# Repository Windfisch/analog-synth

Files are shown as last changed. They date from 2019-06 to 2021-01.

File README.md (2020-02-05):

# Analog Synthesizer Project

This project attempts to build a **low-cost** analog synthesizer based on
well-available components like LM324 or TL084 op-amps, which is **easy
to understand and learn**.

The goal is a semimodular synthesizer which is compatible to existing other
systems, where possible. The following features are planned:

- two 1-Volt-per-octave voltage controlled oscillators (VCO) with triangle,
  PWM-able square, and sawtooth waveforms
- the option to use them as digital controlled oscillators (DCO)
- a voltage controlled filter (VCF)
- a voltage controlled amplifier (VCA)
- digital or analog envelope generators
- analog waveshaping and distortion circuits
- USB or MIDI interface based on a STM32 microcontroller

For the sake of simplicity, the following trade-offs are being made:

- exact component selection is traded for automatic or semiautomatic tuning
  where possible:
- no exact 1-volt-per-octave frequency behaviour: The VCO's frequency response
  is not 100% perfect. While commercial synthesizers offer complex analog
  compensation circuitry, this project will measure the frequency deviation
  and compensate for it in software at the stage of the
  MIDI-to-Control-Voltage interface.
- no voltage controlled analog envelopes: These are complicated to build, and
  the difference to digital envelopes or LFOs is not noticeable.

## Required Hardware

So far, apart from standard resistors and capacitors, the synth uses LM324 op
amps, and BC547 / 2N3904 bipolar-junction-transistors and 2N7000 MOSFETs.

The control logic and its firmware is currently based upon a STM32F103 based
*"blue pill"* board, which can be sourced for less than 2 EUR from your
favourite chinese seller. ([Note: look for those boards with a rectangular white reset
switch, not a flat round one.](bluepill.md))
Previous versions were developed for the
[STM32F411 discovery board](https://www.st.com/en/evaluation-tools/32f411ediscovery.html),
which should still work after adjusting the Makefile.

## Repo Contents

under `simulation/`, some circuitry was tested (using the KiCAD SPICE
simulation).

Most importantly, `simulation/vco` shows a functional exponential VCO. There
are detailed annotations on which part serves which purpose.

[simulation/software/](simulation/software/) contains tooling to do transient
simulation on parts of the synth with different control voltages and to further analyze
the results.

Under `measure_vco/` you can find the tooling and test results for measuring
the pitch deviation of the VCO.

[hardware/](hardware/) contains the actual hardware boards and drafts:

  - The [VCO development board mk I](hardware/vco_mk1).
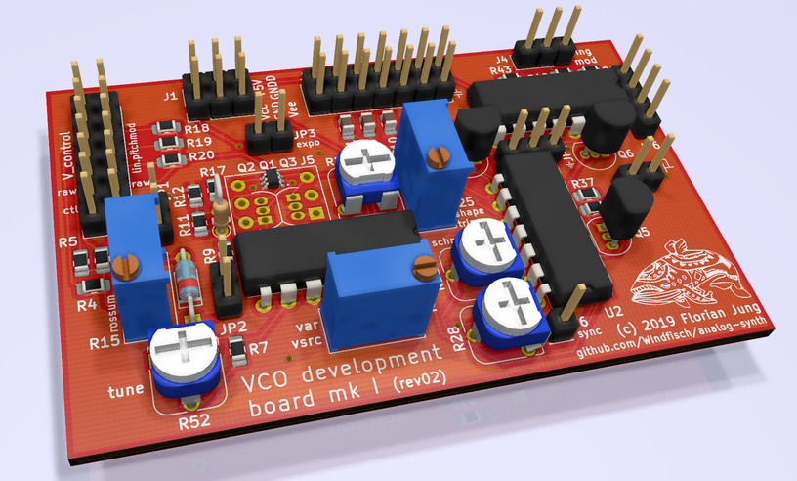
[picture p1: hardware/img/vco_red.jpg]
    
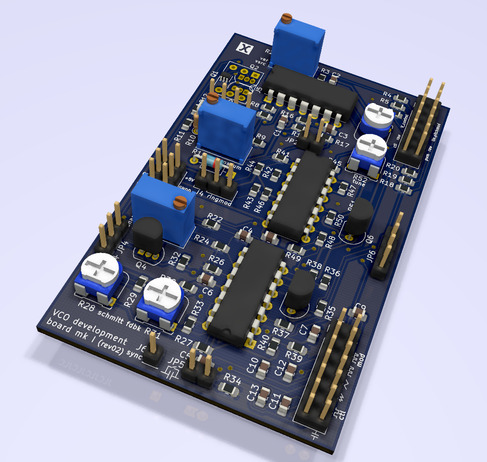
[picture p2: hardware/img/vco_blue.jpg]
    
  - A [voice supplement board](hardware/voice_board) containing a VCA, VCF and
    some utility functions.
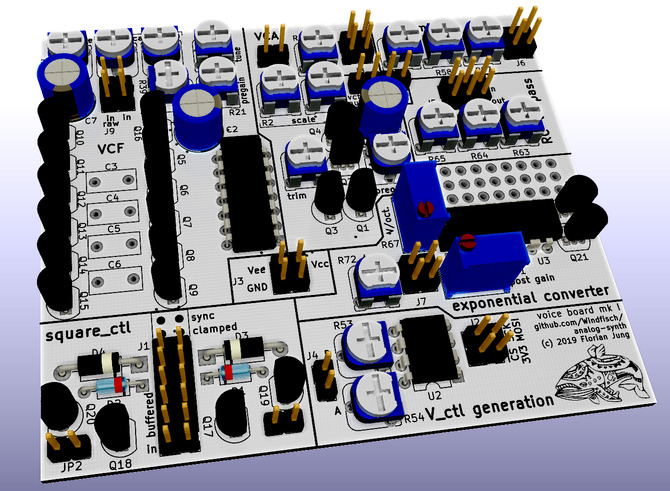
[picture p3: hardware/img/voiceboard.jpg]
render of the board
    
  - A [main control board](hardware/control_board_prototype) with a STM32 blue
    pill board, utility DACs and the supply voltage generation.
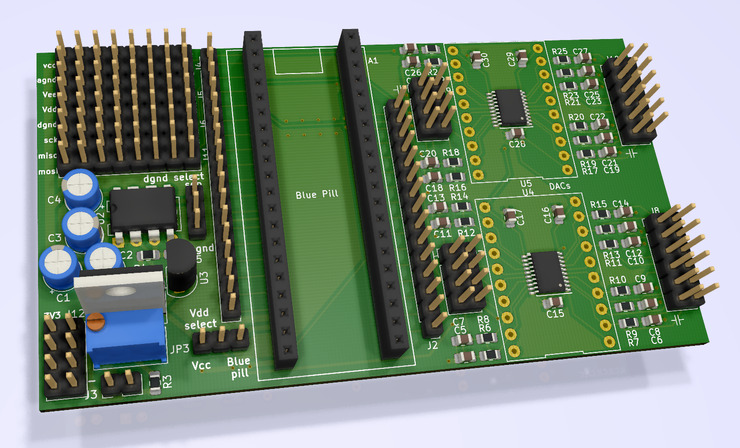
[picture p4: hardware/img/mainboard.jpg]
render of the board
    

## Setup

To build libopencm3:

```
git submodule update --init
make -j8 -C libopencm3
```

If you're using a STM32F411 board, you must adjust `measure_vco/firmware/Makefile`
and use the `DEVICE=stm32f411re` instead of the `DEVICE=stm32f103c8t` line.

To measure the vco frequency response:

```
cd measure_vco/firmware
make
```

then do whatever is neccessary to flash the program onto your board. For the blue
pill board, putting it into bootloader mode by jumpering BOOT0 to 1, resetting, and
calling `stm32flash -w dac_test.bin /dev/ttyUSB0` does the job, while for my
STM32F411-discovery, which has a non-standard blackmagic firmware on the STLINK chip, it is:

```
arm-none-eabi-gdb dac_test.elf # make sure it loads the .gdbinit file
load
run
```

Connect the pins correctly, then record the output with an UART adapter
(or using the blackmagic uart device).

## Licensing

All software, firmware and schematics are released under the terms of the [GPL3 license](LICENSE.md).
Note that this does not include the `simulation/**/*.lib` files needed for
simulation. Vendor licensing as noted in the respective files applies.

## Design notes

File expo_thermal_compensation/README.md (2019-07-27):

# Designing a thermal compensation for the exponential converter

The exponential converter used in the VCO has a temperature dependency that
affects its volt-per-octave setting. To be precise, the expo converter
is described by the following formula:

```
I_out = const * exp(V_in / V_T)
```

where `V_T` denotes the _thermal voltage_ of the transistor, which is
calculated as

```
V_T = k * T / q
```

with `k` being the [Boltzmann Constant](https://en.wikipedia.org/wiki/Boltzmann_constant),
`T` denoting the temperature in [Kelvin](https://en.wikipedia.org/wiki/Kelvin) and
`q` being the [elementary charge](https://en.wikipedia.org/wiki/Elementary_charge).

This means that since room temperature is roughly at 300K = 27C, a change in temperature
by 3 degrees changes the argument of exp(...) by ±1%. So at 24C, our 1V/oct VCO may
actually require only 0.99V/oct, and at 30C, it may need 1.01V/oct.

Over a range of plus minus three octaves, the highest and lowest note would be
`1200 * 3 * 0.01` = 36 cents off!

## Compensating using a NTC

In order to compensate for this, we can employ a resistor network containing
an NTC resistor, that changes its resistance in dependence of the temperature.

Instead of feeding the actual control voltage into the expo converter, we run it
through a voltage divider which counteracts the transistor behaviour.

The network looks as follows, with R3 being the NTC. The control voltage is fed
into `(in)`, while `(out)` goes into the expo converter.

```
                 +----[R2]----+
(in) ----[R1]----+            +------+----- [R4] ---- GND
                 +----[R3]----+      |
                                   (out)
```

## Finding the right values

A commonly available NTC is the
[Vishay NTCLE100E3 series](https://www.vishay.com/docs/29049/ntcle100.pdf).

Their datasheet describes their resistance using the following formula:

```
R_T = R_ref * exp(A + B/T + C/T² + D/T³)
```

where A,B,C and D are listed in the table on page four. The values differ
for different `R_ref` values as described in the datasheet.

`find_values.py` performs a brute-force search over possible values for
R1 to R4 and outputs a list of possible combinations and their maximum
deviation.

Using this approach, up to 0.3 cent per octave deviation can be achieved
over a temperature range from 18 to 30 degrees celsius.

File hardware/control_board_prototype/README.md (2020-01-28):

Control Board mk I
==================

The main board of the synth: It accepts a STM32F103 Blue Pill board and offers
two 10-channel DACs. Additionally, it contains a voltage converter, a virtual
ground circuit and pin headers for power distribution.

render of the board

Setup
-----

Adjust to R2 to 540 Ohms to get a supply voltage of 10V.

U3 is optional. If U3 is equipped, do not close JP1. (C1, C2, R4 and R5 can
be left out in this case.) Otherwise, do close JP1.

JP2 controls whether the digital ground is connected to the analog ground, or
whether DGND is a separate buffered voltage source.

Similarly, JP3 allows to switch between the analog supply voltage and the
blue pill board's 5V supply voltage.

Recommended configuration
-------------------------

**Use Vdd = Vcc (JP3).** Taking Vdd from the blue pill board creates weird
"digital singing" on the audio signal.

**Use a separate dgnd (JP2).** Joining agnd and dgnd together causes strong
humming (approx. 100Hz; I measured 116Hz?!) and buzzing (from the SPI
bus; completely goes away as long the BU2505FV DAC isn't used (i.e.,
during startup/init), reduced when the MCP4822 isn't connected to the
SPI bus, very present when it is). Using a separate GND completely
cancels the humming, and reduces the buzzing to ~-70-80dB when the
VCA is closed, but still audible if the VCA is open).

A **TLE2426** ground splitter (U3) seems to be **unneccessary**.

Revisions
---------

- rev01: Has no marking and no wind fish on the back side.
- rev02: Small overlapping silk screen fixes. Has a wind fish and "rev02" on the back side. Was never fabricated.

Tested configuration
--------------------

rev01 has been used successfully with the following configuration:

- U2 was changed to TL072.
- JP1 closed, U3 not equipped.
- JP2 (dgnd select) in *sep* configuration.
- JP3 (Vdd select) in *blue pill* configuration.
- right half of the DAC section (i.e. J8, J10 and associated resistors
  and capacitors) not populated.

Fabrication
-----------

The gerber outputs used for fabrication of rev01 with [JLCPCB](https://jlcpcb.com) are
located under `fab/`.

The fabrication layers indicating which component values to put where
are [here](../voice_and_control_board_fab.pdf).

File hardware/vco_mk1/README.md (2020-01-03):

VCO development board mk I
==========================

This board is designed to test several options for the VCO design. It
features:

  - Triangle, pulse and sawtooth wave generation
  - shape adjust (R25). Tune this so that you get a perfect triangle.
  - volt-per-octave input
  - linear and exponential frequency modulation
  - selectable capacitor-coupling for the triangle wave using JP5
  - Boundary adjust: R27-R31. (Increases triangle amplitude while
    lowering its frequency)
  - Rossum compensation ([details](https://www.schmitzbits.de/expo_tutorial/)
    [(or on archive.org)](https://web.archive.org/web/20191216173852/https://www.schmitzbits.de/expo_tutorial/))
    for compensating the pitch drop at higher pitches. Can be enabled by
    closing JP2 and disabled by closing JP1 instead. Optionally, R13-15 and
    D1 need not be equipped when disabled
  - Low frequency trim by connecting Q4's source to some millivolts around
    GND instead of GND directly using JP4. Optionally, R1-R3 can be spared
    if not used.
  - DCO mode by applying a square wave to ctl\_override in J2
  - soft sync mode by applying a narrow open-drain pulse to J6
    (e.g. 99% high impedance, 1% connected-to-GND)
  - Digital ringmodulation on the triangle/sawtooth and the square wave,
    configured through JP6 as follows:
    
    - close 12 and 34 for ring-modulated sawtooth
    - close 12 only for ring-modulated triangle
    - close 23 for no ring modulation. U3, Q6 and R41-50 need not be
      equipped then.

There are two different board layouts:

  - [one smaller double-sided layout](vco_mk1_windfisch)
    render of the board
  - [one larger layout with components only on the top side](vco_mk1_spitfire), contributed by [SpitfireX](https://github.com/spitfirex).
    render of the board

Revisions
---------

**rev01** can be identified by the marking _"VCO development board mk I"_
(without revision id). Both layouts have been fabricated by [JLCPCB](https://jlcpcb.com)
using the gerber outputs in `gerber-rev01/` or `fab-rev01/`.
Please see the Errata below.

**rev02** can be identified by the text _"VCO development board mk I (rev02)"_.
It has never been fabricated as it contains only silk screen bug fixes.
The differences to rev01 are:

  - U2 is rotated by 180 degrees, swapping U2A/U2C and U2B/U2D, respectively.
  - The pictograms around J3 have been rearranged in the correct order.

Errata (rev01)
--------------

U2 has Vcc and Vee swapped in the schematic. This can be resolved by inserting
U2 into the socket "the wrong way" (i.e. the notch is not on the side where the
PCB wants to have the notch).

SpitfireX's board has the pictograms around J3 reversed. This affects both
the signal pictograms as well as the marking for the capacitor-coupled outputs.

These are fixed in rev02.

Differences from the schematic (rev01)
--------------------------------------

  - U2 is reversed (see Errata)
  - Q1 was equipped, J5, Q2 and Q3 weren't
  - R2 was replaced by a 20k poti
  - R15 was not equipped (no rossum compensation)
  - R18-20 were not equipped yet
  - R10 is missing (no thermal compensation)
  - R9 was replaced by a 100 Ohm resistor
  - R8 was replaced by 10k
  - R4,5,6 were populated with 470k, 220k and 100k, respectively

Testing the board
-----------------

1. Do not equip R15. Close JP1, but not JP2 to disable the rossum compensation.
2. Do not equip U3, and put a jumper on JP6's pins 2+3 to disable ring modulation.
3. Put a jumper on JP4 so that GND is connected.
4. Connect Vcc, GND and Vee to +6V, 0V and -6V (approx.). This configuration can be
   achieved e.g. by a 12 V voltage source, a 1:1 resistor divider and a LM324/LM358
   in buffer configuration for GND.
5. Connect the capacitor-coupled triangle output on J3 to your sound card. Connect GND
   via a capacitor to your sound card.
6. You should hear a triangle wave that can be tuned with R52, R21 (and R31).

Further usage scenarios
-----------------------

### Using the pwm input

The PWM comparator's input is floating. Either connect a voltage source / poti to it that
can range from Vee to Vcc, or tie it to GND using a jumper on J2.

### Tuning the center frequency

Close the JP3 jumper. This will disable the control voltage input and force it to the
"center position". R52 (tune) will be useless. R21 can be used to tune the frequency
at the center position. This is the pitch where the oscillator will exhibit no thermal
drift; the "V/oct" drift (which is compensated by R9-R12, but not perfectly) will
develop around the center pitch. The farther away from this center pitch, the worse the
drift will be.

### Adjusting the schmitt trigger's operation

The triangle's amplitude and pitch can be adjusted by R31.

The triangle's center voltage can be adjusted with R28. This is only relevant when JP5 is
closed, directly attaching the triangle signal to the sawtooth generation circuitry,
bypassing the coupling capacitor. In this case, tuning R28 is required to achieve a clean
sawtooth signal where all teeth are at the same voltage levels.

### Tuning the frequency response

By equipping the Rossum compensation circuitry, closing JP2 and opening JP1, Rossum
compensation can be tuned using R15. This changes the frequency response at high pitches.

By not jumpering GND, but the variable voltage source on JP4, R2 can be used to affect
the frequency response at low pitches.

### Square-like waveform

Connect `square_ctl` to the ring mod input J4. Ideally do not connect it directly,
but buffer the signal using an emitter follower or similar. Loading `square_ctl` will
severly affect the pitch. Then listen to the pulse-mod signal while changing the pwm
voltage on J2.

Soldering workflow
------------------

I soldered the boards in my [local FabLab](https://fablab.fau.de), using a thermal
controlled soldering iron with a flat (screwdriver-like) tip (maybe 1-2mm wide).

I had a printed [BOM](vco_mk1_windfisch/bom.ods) next to me, where I ticked
every component.

Notes for various components:

  - *Resistors and capacitors*: for each component value, do:
    - for each occurence do:
      1. put some tin on one of the pads
      2. heat the tinned pad while sliding the component onto the pad
      3. solder the other pad
    - difficulty: easy
  - *BCM847*: using a stereo microscope, do:
    - 1. use *lots* of flux
    - 2. put some tin on a pad, slide the component onto it
    - 3. more flux
    - 4. solder all pins of the opposite side. Ignore any solder bridges
    - 5. same for the other side.
    - 6. remove the solder bridges by applying flux, then sliding the cleaned
         soldering iron away from the pins. This will take away some tin, until
         finally the solder bridge vanishes due to the surface tension.
    - difficulty: advanced with good equipment, impossible without
  - *through hole components*: straightforward, easy. Order them from flat to large.

Lessons learned
---------------

A capacitor-coupled GND terminal would be useful.

When connecting `square_ctl` to J6 (regardless of whether U3 is installed or not),
this affects the frequency by ca. a semitone. A transistor buffer might help.

Finding the component locations is hard. Prepare one copy of the board layout
per component value, with the respective components highlighted. (Maybe color
coding helps to reduce the amount of copies needed).

Greatly reduce the amount of different component values. Finding the right
component strip and peeling of the covering foil off takes a lot of time.

It might be better to prepare all resistors/capacitors at once, instead of
grouping them by value. Color coding might help.

The double-sided variant wasn't slower to solder than the single-sided.

The BC547 transistor pair don't touch, the footprint should move a bit towards
each other.

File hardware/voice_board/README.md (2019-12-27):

Voice Board mk I
================

This board offers various utility features for a two-VCO-voice. It is designed
to be used together with two [../vco_mk1/](VCO mk I boards) and offers the
following features:

  - voltage controlled filter
  - voltage controlled amplifier
  - simple mixer
  - 2x square_ctl signal processing (buffering, sync pulse generation, clamping,
    which are missing from the VCO mk I board)
  - an expo converter (to be used as VCF input)
  - a 2-channel MCP4822 DAC for VCO control voltage generation
  - three general-purpose RC low pass filters

render of the board

The gerber outputs used for fabrication with [JLCPCB](https://jlcpcb.com) are
located under `fab/`.

The fabrication layers indicating which component values to put where
are [here](../voice_and_control_board_fab.pdf).

Revisions
---------

**rev01** has no marking at the wind fish logo. It has been fabricated
using the gerber outputs in `fab-rev01/`. Please refer to the errata
below.

**rev02** can be identified by a *"rev02"* text close to the wind fish
logo. It has never been fabricated as it only contains silkscreen and
component value fixes.

Errata (rev01)
--------------

Some resistors in the sync pulse circuitry are wrong. R48 and R49 must
be changed from 10k to 1k. R50 and R51 must be changed from 1k to 10k.
This has been fixed in rev02.

R53 and R54's values are too weak, leading to very bad DAC performance
(e.g., non-monotonic DAC behaviour every 4 code points). Maybe a 100k
poti would work better; I fixed it by de-soldering the potis and wiring
U2's DAC output pins 6 and 8 to the connector J4 directly.

Errata (rev01)
--------------

R53 and R54's values are too weak, leading to very bad DAC performance
(e.g., non-monotonic DAC behaviour every 4 code points). Maybe a 100k
poti would work better; I fixed it by de-soldering the potis and wiring
U2's DAC output pins 6 and 8 to the connector J4 directly.

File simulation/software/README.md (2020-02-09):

Simulation analysis tooling
===========================

This tooling is intended to do transient simulation for various control
voltages using ngspice and to analyze the resulting time series.

GNU parallel is recommended for faster execution.

Usage
-----

To generate the netlist: Open `../vco/` in KiCAD, and export a netlist in spice format
(`vco.cir`).

To generate the joblist:

`bash generate_joblist.sh ../vco/vco.cir V2 0 5 0.5 sawtooth triangle square_ctl  > /tmp/jobs.txt`

The joblist can be executed with either `parallel < /tmp/jobs.txt` or `bash /tmp/jobs.txt`.

Results are placed in `/tmp/analog-synth-spice/`.

tooling for further analysis: run `bash generate_joblist.sh ../vco/vco.cir v2 -2 2.8 0.1 triangle sawtooth square_ctl V_control V_expo GNDREF`

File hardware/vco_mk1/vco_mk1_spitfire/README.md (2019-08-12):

Alternative PCB layout by [SpitfireX](https://github.com/spitfirex).

This design is a 2 layer PCB with all components on the front. As a result, it features a continuous ground plane on the back.

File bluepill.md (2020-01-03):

Buying the right blue pill board
================================

It appears that blue pill boards are available from at least two different
manufacturers.

- The "white switch" variant has a rectangular, high-profile white reset
  switch located close to the USB port. Also, the USB port has two mounting
  pads (one at each side). The silk screen is layouted carefully.
  bad board
- The "round switch" variant has a flat and round reset switch at the same
  location. The USB port has four mounting pads. The silk screen at the pin
  headers ("B12 B13...") is uneven, the letters don't share a common baseline.
  good board

While both variants are affected by the
[wrong USB resistor issue](https://amitesh-singh.github.io/stm32/2017/05/27/Overcoming-wrong-pullup-in-blue-pill.html)
[(or on archive.org)](https://web.archive.org/web/20190401142745/https://amitesh-singh.github.io/stm32/2017/05/27/Overcoming-wrong-pullup-in-blue-pill.html)
(tl;dr: The USB D+ pull up resistor R10 should be 1.5k, but it's populated with
10k. Some hosts don't like this, others don't care), I never had a problem with
this.

However, the "round switch" variant appears to be of worse build quality: All two
boards I bought failed to provide reliable USB connectivity, one even failed to
provide a reliable +5V power to the STM32.

I had no problems with my four samples of the "white switch" variant, so I
recommend using these.

[See also](https://wiki.relativty.net/index.php/STM32#Purchasing_your_STM32_board)
[(or on archive.org)](https://web.archive.org/web/20200103224615/https://wiki.relativty.net/index.php/STM32)

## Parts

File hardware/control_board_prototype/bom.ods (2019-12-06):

Ref | Qnty | Value | Cmp name | Footprint | Description | Vendor
A1, | 1 | BluePill | BluePill | footprints:BLUEPILL
J1, | 1 | Conn_01x17_Male | Conn_01x17_Male | Connector_PinHeader_2.54mm:PinHeader_1x17_P2.54mm_Vertical | Generic connector, single row, 01x17, script generated (kicad-library-utils/schlib/autogen/connector/)
J2, | 1 | Conn_01x15_Male | Conn_01x15_Male | Connector_PinHeader_2.54mm:PinHeader_1x15_P2.54mm_Vertical | Generic connector, single row, 01x15, script generated (kicad-library-utils/schlib/autogen/connector/)
 | 32 | One-row pin socket
J3, | 1 | Conn_01x02_Male | Conn_01x02_Male | Connector_PinHeader_2.54mm:PinHeader_1x02_P2.54mm_Vertical | Generic connector, single row, 01x02, script generated (kicad-library-utils/schlib/autogen/connector/)
JP1, | 1 | SolderJumper_2_Open | SolderJumper_2_Open | windfisch:SolderBridge | Solder Jumper, 2-pole, open
JP2, JP3, | 2 | Jumper_3_Bridged12 | Jumper_3_Bridged12 | footprints:SolderDipJumper3alt | Jumper, 3-pole, pins 1+2 closed/bridged
 | 42 | One-row pin header
J7, J9, J12, | 3 | Conn_02x04_Odd_Even | Conn_02x04_Odd_Even | Connector_PinHeader_2.54mm:PinHeader_2x04_P2.54mm_Vertical | Generic connector, double row, 02x04, odd/even pin numbering scheme (row 1 odd numbers, row 2 even numbers), script generated (kicad-library-utils/schlib/autogen/connector/)
J8, J10, | 2 | Conn_02x06_Odd_Even | Conn_02x06_Odd_Even | Connector_PinHeader_2.54mm:PinHeader_2x06_P2.54mm_Vertical | Generic connector, double row, 02x06, odd/even pin numbering scheme (row 1 odd numbers, row 2 even numbers), script generated (kicad-library-utils/schlib/autogen/connector/)
J11, J6, J4, J5, | 4 | Conn_02x10_Odd_Even | Conn_02x08_Odd_Even | Connector_PinHeader_2.54mm:PinHeader_2x08_P2.54mm_Vertical | Generic connector, double row, 02x08, odd/even pin numbering scheme (row 1 odd numbers, row 2 even numbers), script generated (kicad-library-utils/schlib/autogen/connector/)
 | 74 | Two-row pin header
C1-C4 | 4 | 1u | CP | Capacitor_THT:CP_Radial_D5.0mm_P2.50mm | Polarized capacitor
C5-C30 | 26 | 100n | C | Capacitor_SMD:C_0805_2012Metric_Pad1.15x1.40mm_HandSolder | Unpolarized capacitor
R1, | 1 | 220 | R | Resistor_SMD:R_0805_2012Metric_Pad1.15x1.40mm_HandSolder | Resistor
R2, | 1 | 1k | R_Variable | Potentiometer_THT:Potentiometer_Bourns_3296W_Vertical | Variable resistor
R3, | 1 | 1k | R | Resistor_SMD:R_0805_2012Metric_Pad1.15x1.40mm_HandSolder | Resistor
R5, R4, | 2 | 100k | R | Resistor_SMD:R_0805_2012Metric_Pad1.15x1.40mm_HandSolder | Resistor
R6-R25 | 20 | 10k | R | Resistor_SMD:R_0805_2012Metric_Pad1.15x1.40mm_HandSolder | Resistor
U1, | 1 | LM317 | LM317_3PinPackage | Package_TO_SOT_THT:TO-220-3_Vertical | 1A 35V Adjustable Linear Regulator, SOT-89/SOT-223/TO-220/TO-252/TO-263
U2, | 1 | LM358 | LM358 | Package_DIP:DIP-8_W7.62mm | Low-Power, Dual Operational Amplifiers, DIP-8/SOIC-8/TO-99-8
U3, | 1 | TLE2426xLP | TLE2426xLP | Package_TO_SOT_THT:TO-92L_Inline | Precision virtual ground, 4V to 40V input, TO-92
U4, U5, | 2 | BU2505FV | BU2505FV | footprints:SSOP20_and_breakout

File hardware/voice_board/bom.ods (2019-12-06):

Ref | Qnty | Value | Cmp name | Footprint | Description | Vendor
C1, | 1 | 470n | CP | Capacitor_THT:CP_Radial_D7.5mm_P2.50mm | Polarized capacitor
C2, C7, | 2 | 470u | CP | Capacitor_THT:CP_Radial_D7.5mm_P2.50mm | Polarized capacitor
C3, C4, C5, C6, | 4 | 47n | C | footprints:C_rect_smd_combo | Unpolarized capacitor
C8, C9, | 2 | 1n | C | Capacitor_SMD:C_0805_2012Metric_Pad1.15x1.40mm_HandSolder | Unpolarized capacitor
C10, C11, C17, | 3 | 1u | C | Capacitor_SMD:C_0805_2012Metric_Pad1.15x1.40mm_HandSolder | Unpolarized capacitor
C13, C14, C15, | 3 | any | C | Capacitor_SMD:C_0805_2012Metric_Pad1.15x1.40mm_HandSolder | Unpolarized capacitor
C16, | 1 | 10n | C | Capacitor_SMD:C_0805_2012Metric_Pad1.15x1.40mm_HandSolder | Unpolarized capacitor
D1, D2, | 2 | 3V3 | D_Zener | Diode_THT:D_DO-35_SOD27_P7.62mm_Horizontal | Zener diode
D3, D4, | 2 | 1N5817 | 1N5817 | Diode_THT:D_DO-41_SOD81_P10.16mm_Horizontal | 20V 1A Schottky Barrier Rectifier Diode, DO-41
J1, | 1 | Conn_02x06_Odd_Even | Conn_02x06_Odd_Even | Connector_PinHeader_2.54mm:PinHeader_2x06_P2.54mm_Vertical | Generic connector, double row, 02x06, odd/even pin numbering scheme (row 1 odd numbers, row 2 even numbers), script generated (kicad-library-utils/schlib/autogen/connector/)
J3, J2, J6, J7, J9, J8, | 6 | Conn_02x02_Odd_Even | Conn_02x02_Odd_Even | Connector_PinHeader_2.54mm:PinHeader_2x02_P2.54mm_Vertical | Generic connector, double row, 02x02, odd/even pin numbering scheme (row 1 odd numbers, row 2 even numbers), script generated (kicad-library-utils/schlib/autogen/connector/)
J5, | 1 | Conn_02x03_Odd_Even | Conn_02x03_Odd_Even | Connector_PinHeader_2.54mm:PinHeader_2x03_P2.54mm_Vertical | Generic connector, double row, 02x03, odd/even pin numbering scheme (row 1 odd numbers, row 2 even numbers), script generated (kicad-library-utils/schlib/autogen/connector/)
 | 21 | Two-row pin header
J4, J10, | 2 | Conn_01x02_Male | Conn_01x02_Male | Connector_PinHeader_2.54mm:PinHeader_1x02_P2.54mm_Vertical | Generic connector, single row, 01x02, script generated (kicad-library-utils/schlib/autogen/connector/)
JP1, JP2, | 2 | Jumper_2_Bridged | Jumper_2_Bridged | footprints:SolderDipJumper2alt | Jumper, 2-pole, closed/bridged
JP3, | 1 | Conn_01x04_Male | Conn_01x04_Male | footprints:SolderDipJumper4alt | Generic connector, single row, 01x04, script generated (kicad-library-utils/schlib/autogen/connector/)
 | 12 | One-row pin header
Q3, Q1, | 2 | BC327 | BC327 | Package_TO_SOT_THT:TO-92_Inline | 0.8A Ic, 45V Vce, PNP Transistor, TO-92
Q4-Q16 | 14 | BC557 | BC557 | Package_TO_SOT_THT:TO-92_Inline | 0.1A Ic, 45V Vce, PNP Small Signal Transistor, TO-92
Q17-Q21, | 4 | BC547 | BC547 | Package_TO_SOT_THT:TO-92_Inline | 0.1A Ic, 45V Vce, Small Signal NPN Transistor, TO-92
Q19, Q20, | 2 | 2N7000 | 2N7000 | Package_TO_SOT_THT:TO-92_Inline | 0.2A Id, 200V Vds, N-Channel MOSFET, 2.6V Logic Level, TO-92
R8, R46, R22, R50, R47, R51, R70, | 7 | 1k | R | Resistor_SMD:R_0805_2012Metric_Pad1.15x1.40mm_HandSolder | Resistor
R10, R9, R11, R44, R41, R37, R36, R60, R61, R38, R48, R45, R49, R62, | 14 | 10k | R | Resistor_SMD:R_0805_2012Metric_Pad1.15x1.40mm_HandSolder | Resistor
R13, R12, | 2 | 20k | R | Resistor_SMD:R_0805_2012Metric_Pad1.15x1.40mm_HandSolder | Resistor
R17, R23, R24, R33, R14, R6, R4, R3, R66, R15, | 10 | 100k | R | Resistor_SMD:R_0805_2012Metric_Pad1.15x1.40mm_HandSolder | Resistor
R25, | 1 | 47k | R | Resistor_SMD:R_0805_2012Metric_Pad1.15x1.40mm_HandSolder | Resistor
R26, | 1 | 180 | R | Resistor_SMD:R_0805_2012Metric_Pad1.15x1.40mm_HandSolder | Resistor
R27, R35, | 2 | 470 | R | Resistor_SMD:R_0805_2012Metric_Pad1.15x1.40mm_HandSolder | Resistor
R30, R29, R28, R31, | 4 | 150 | R | Resistor_SMD:R_0805_2012Metric_Pad1.15x1.40mm_HandSolder | Resistor
R32, | 1 | 220 | R | Resistor_SMD:R_0805_2012Metric_Pad1.15x1.40mm_HandSolder | Resistor
R34, | 1 | 680 | R | Resistor_SMD:R_0805_2012Metric_Pad1.15x1.40mm_HandSolder | Resistor
R43, R42, R69, | 3 | 1Meg | R | Resistor_SMD:R_0805_2012Metric_Pad1.15x1.40mm_HandSolder | Resistor
R68, | 1 | 2.5k | R | Resistor_SMD:R_0805_2012Metric_Pad1.15x1.40mm_HandSolder | Resistor
R5, | 1 | 200k | RTRIM | Potentiometer_THT:Potentiometer_Runtron_RM-065_Vertical | Trimmable resistor (preset resistor)
R7, R40, R16, R20, | 4 | 100k | R_POT | Potentiometer_THT:Potentiometer_Runtron_RM-065_Vertical | Potentiometer
R21, | 1 | 1Meg | R_Variable | Potentiometer_THT:Potentiometer_Runtron_RM-065_Vertical | Variable resistor
R53, R54, | 2 | 1k | R_POT | Potentiometer_THT:Potentiometer_Runtron_RM-065_Vertical | Potentiometer
R57, R58, R39, R1, R59, R72, R2, R19, R18, | 9 | 10k | R_POT | Potentiometer_THT:Potentiometer_Runtron_RM-065_Vertical | Potentiometer
R65, R64, R63, | 3 | any | R_Variable | Potentiometer_THT:Potentiometer_Runtron_RM-065_Vertical | Variable resistor
R67, | 1 | 200k | RTRIM | Potentiometer_THT:Potentiometer_Bourns_3296W_Vertical | Trimmable resistor (preset resistor)
R71, | 1 | 10k | RTRIM | Potentiometer_THT:Potentiometer_Bourns_3296W_Vertical | Trimmable resistor (preset resistor)
U1, | 1 | TL074 | TL074 | Package_DIP:DIP-14_W7.62mm | Quad Low-Noise JFET-Input Operational Amplifiers, DIP-14/SOIC-14
U2, | 1 | MCP4822 | MCP4822 | Package_DIP:DIP-8_W7.62mm | 2-Channel 12-Bit D/A Converters with SPI Interface and Internal Reference (2.048V)
U3, | 1 | LM324 | LM324 | Package_DIP:DIP-14_W7.62mm | Low-Power, Quad-Operational Amplifiers, DIP-14/SOIC-14/SSOP-14

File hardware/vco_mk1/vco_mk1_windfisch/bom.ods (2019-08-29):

Reference | Quantity | Value | Footprint | Datasheet
C4 | 1 | 1n | 0805 | ~
C3 | 1 | 2.2n | 0805 | ~
C1 C2 C5 C6 C7 C8 C9 C10 C11 C12 C13 | 11 | 100n | 0805 | ~
J6 | 1 | Conn_01x01_Male | Conn_01x01_Male | ~
J1 J4 | 2 | Conn_01x03_Male | Conn_01x03_Male | ~
J2 J3 | 2 | Conn_02x07_Male | Conn_02x07_Male | ~
D1 | 1 | 1N4148 | DO-35 | https://assets.nexperia.com/documents/data-sheet/1N4148_1N4448.pdf
JP1 JP2 JP3 JP5 | 4 | Conn_01x02_Male | footprints:SolderDipJumper2alt | ~
JP4 | 1 | Conn_01x03_Male | footprints:SolderDipJumper3alt | ~
JP6 | 1 | Conn_01x04_Male | footprints:SolderDipJumper4alt | ~
U1 U2 | 2 | LM324 | DIP-14 | http://www.ti.com/lit/ds/symlink/lm2902-n.pdf
U3 | 1 | 74HC86 | DIP-14 | http://www.ti.com/lit/gpn/sn74HC86
J5 | 1 | BCM847 breakout socket | DIP6-wide-ish | ~
Q1 | 1 | BCM847 | SOT-363 | http://www.onsemi.com/pub_link/Collateral/BC846BDW1T1-D.PDF
Q4 | 1 | 2N7000 | TO-92 | https://www.fairchildsemi.com/datasheets/2N/2N7000.pdf
Q6 | 1 | BC327 | TO-92 | http://www.onsemi.com/pub_link/Collateral/BC327-D.PDF
Q2 Q3 Q5 | 3 | BC547 | TO-92 | http://www.fairchildsemi.com/ds/BC/BC547.pdf
R15 | 1 | 1k | Potentiometer_Bourns_3296W_Vertical | ~
R2 R25 | 2 | 10k | Potentiometer_Bourns_3296W_Vertical | ~
R52 | 1 | 1k | Potentiometer_Runtron_RM-065_Vertical | ~
R28 | 1 | 20k | Potentiometer_Runtron_RM-065_Vertical | ~
R21 | 1 | 50k | Potentiometer_Runtron_RM-065_Vertical | ~
R31 | 1 | 1Meg | Potentiometer_Runtron_RM-065_Vertical | ~
R9 | 1 | 150 | 0805 | ~
R11 R17 R39 | 3 | 1k | 0805 | ~
R12 R40 | 2 | 2.2k | 0805 | ~
R13 | 1 | 4.7k | 0805 | ~
R27 R29 R32 R35 R41 R42 R43 R48 R49 R50 R51 | 11 | 10k | 0805 | ~
R8 | 1 | 12k2 | 0805 | ~
R23 R24 R26 | 3 | 47k | 0805 | ~
R4 R5 R6 | 3 | 147k | 0805 | ~
R14 R16 R22 R33 R36 R37 R38 R44 R45 R46 R47 | 11 | 100k | 0805 | ~
R7 | 1 | 220k | 0805 | ~
R1 R3 | 2 | 1Meg | 0805 | ~
R30 R34 | 2 | none | 0805 | ~
R18 R19 R20 | 3 | TODO | 0805 | ~
R10 | 1 | 1k NTC | Through-hole | ~

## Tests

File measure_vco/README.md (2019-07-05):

# measuring the VCO's response

This test tool will enumerate all 4096 DAC code points to generate voltages
between 0V and 2.048V which are fed into the VCO. The microcontroller will
test around 50 code points per second, listen to the signal for 5 periods,
and write out a list of the following format to its USART on pin A2:

```
codept  divider hiTicks1 loTicks1  hiTicks2 loTicks2  hiTicks3 loTicks3  hiTicks4 loTicks4  hiTicks5 loTicks5
 718      3      28751    28328     28745    28333     28742    28326     28756    28322     28752    28326
1694      9      36019    36032     36061    35997     35998    36019     36046    36013     36028    36000
3742      1      24342    23752     24350    23754     24342    23756     24340    23756     24354    23762
 414     45      39457    44456     39468    41359     39476    41358     39477    41360     39463    41366
2462      4      29918    29569     29912    29572     29900    29571     29889    29575     29896    29571
...
```

`divider` specifies the `TIM2` timer's division (in fact, it's the prescaler
plus 1). `TIM2` is clocked at 78MHz and will increment every `divider` clocks.

The hi/loTicksN can be converted into seconds by the following formula:
`time[sec] = ticks * divider / 78'000'000`, the frequency can be calculated e.g.
by `1 / (hiTicks5+loTicks5)` or -- even more precise -- `5 / (sum of all hi+loTicks)`.

older versions, which tested only 4 code points per seconds, were using the
following format.
The time is given in 10'000ths of a second. Thus, the frequency is calculated
as "(periods / (time/10000))":

```
DAC code  periods     time
point       
2048         98       2000
1024         68       1977
...
```

In both cases, the output voltage calculates as "code point * 0.5mV".

At the very beginning, two test tones close to the lowest and two close to the
highest control voltage output are played. Use the tune pot R10 to set an
offset at or close to a position where both test pairs can be heard at distinct
pitches to avoid clamping.

## experiments

[Exponential frequency response accuracy](experiments/20190625_1v_per_oct_response/README.md)

[Attribution of error artifacts to DAC or analog circuitry](experiments/20190705_error_attribution/README.md)

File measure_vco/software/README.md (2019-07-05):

Helper Tools and Software
=========================

These tools are intended to support the development process on the PC
side.

analyze\_stability.py
--------------------

This tool will analyze the frequency range, frequency gain and pulse width
behaviour of the VCO. It also supports (currently hardcoded) compensation of
the DAC "wiggle" described [here](../experiments/20190705_error_attribution).

Upon execution it will draw a plot showing the frequency deviation and the
pulse width. Also, it will output the following:

```
[2.25283296e+00 4.93029015e+03]
532.66 code points = 0.2601 Volt per octave
starting at   17.25 Hz =  -5607c distance from a4@440Hz
ending   at 3561.44 Hz =  +3620c distance from a4@440Hz
```

The numbers in the brackets define the *cent per one codepoint* and *cent offset*,
the rest should be self-explanatory.

**Usage:** `analyze_stability.py usart-dump.txt`

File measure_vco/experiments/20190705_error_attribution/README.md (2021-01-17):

Attributing errors to the DAC and to the remaining circuitry
============================================================

The frequency deviation plots show some systematic error in frequency:

First, there is a wiggle every 64 code points or so. Second, the curve
is bowl-shaped, i.e. the volt-per-octave behaviour is not constant over
the whole DAC range. Instead, it approaches a maximum, and at the left and
right of that maximum, the frequency drops flat.

It shall evaluated which of these artifacts can be attributed to the DAC
and which are to be attributed to the remaining circuitry behind the dac.

Experimental setup
------------------

Schematic and firmware from `6a28ec80e1b361b0f84615ae8e1e478800edd393`
are used. The tune pot R10 is initially adjusted so that the full range
up to the VCO's highest frequency is covered by the DAC's range. The
frequency curve was recorded into `run1.txt`.

Then, the tune pot was tuned down (`run2.txt`), even more down (`run3.txt`),
and way up (so that the high frequencies are clipped, `run4.txt`).

The resulting deviation curves are then moved along the graph (it's valid to
move a curve right by X if you move it down by the same amount X) so that
they match each other as good as possible. The shift amounts are equal to the
tuning caused by the tune pot, and are roughly consistent with the interval
I could hear while tuning.

Expectation
-----------

Any error caused by the DAC should not align across the four curves after
having them aligned as described above. Instead, it should align when
the curves are not moved in X direction. _(Reason: This error would depend
on which code point was sent to the DAC, and not on which voltage went
through U8)_

Any error caused by the circuitry behind the DAC (i.e. expo converter and VCO)
should align across the four curves. _(Reason: It does not depend on the code
point, but solely on the voltage at U8)_

Results
-------

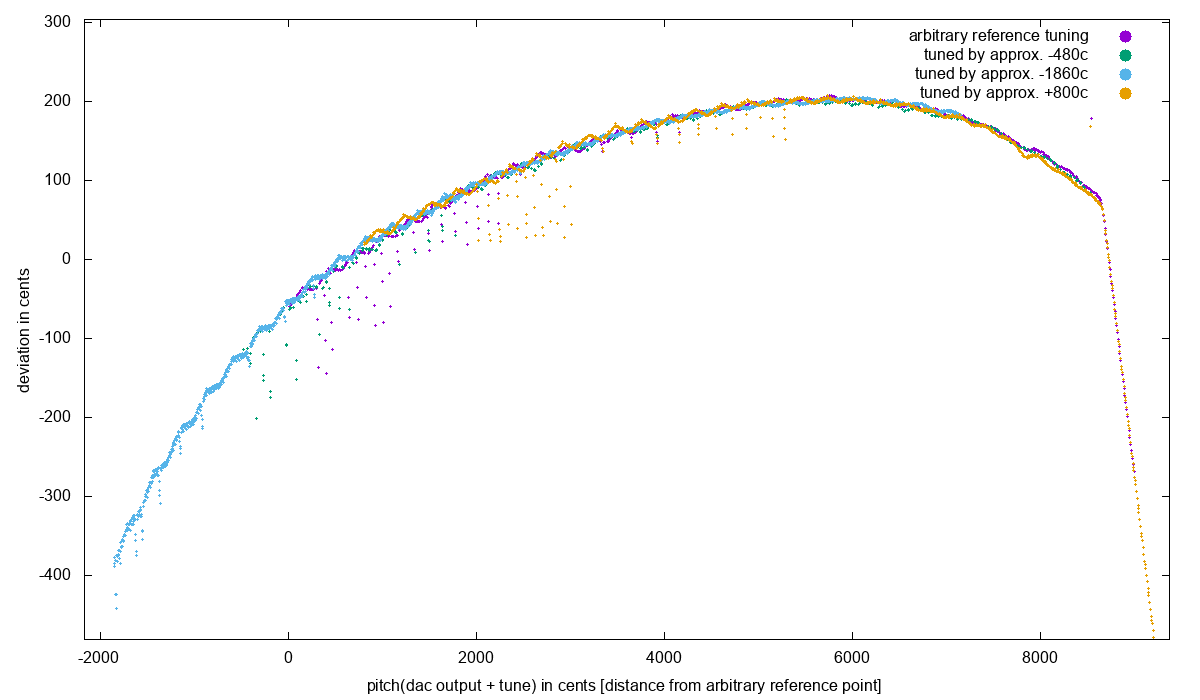
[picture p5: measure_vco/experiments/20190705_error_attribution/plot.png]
plot


The wiggle does not align. Instead, one can easily verify (not shown)
that the wiggle would align perfectly, if the X axis would show the code point,
not something proportional to the voltage through U8.

**The wiggle is a DAC linearity error and must be compensated for in firmware.**
The MCP4822 data sheet confirms this with figure 2-6 which describes "the 64 code
effect".

The overall frequency deviation perfectly aligns across the four curves.
**While it can be compensated for in firmware, it should be adressed in the
analog circuitry. Otherwise, no precise 1v/oct operation with external
(uncompensated) control voltages is possible.**

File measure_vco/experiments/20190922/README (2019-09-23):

breadboard 1: breadboard mit rossum und mit alternativen (blauen) werten fuer widerstaende
breadboard 2: ohne rossum
breadboard 3: blaue werte durch originale ersetzt (1mohm -> 100k und entsprechend das poti)
breadboard3_5.0b und ff: neu getuned.
breadboard 4: thermistor entfernt

Versorgungsspannung: 14.7V, LM317 auf 12V runter. 50-60mA verbrauch
blaues board war angeschlossen

Jumper:
JP2,3,5 offen
JP6 mittig
JP4 masse
JP1 geschlossen

format: name_x.x.{txt,png}

x.x: Amplitude des Signals in V (eingestellt via R31 (schmitt feedback))

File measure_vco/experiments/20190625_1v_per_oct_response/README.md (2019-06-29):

made with ef54a038da6c0d5c126d3517ab873899670ab93a.

All following measurements were made using a 9V block battery to power the
circuit.

```
out*.txt:               various measurements with the hand-matched 547 pair.
                        might or might have not touched the transistors during
                        measurement
2019-05-25_bcm847.txt:  measurements using the bcm847 matched transistor chip.
                        shortly but with decent time after placing the
                        transistors on the board
2019-05-25_pair*.txt:   1-3: same, but using hand-matched BC547b transistors
                        instead: these runs were started shortly after placing
                        them in the board. the runs were done subsequently with
                        almost no delay. i sat next to the setup, so they might
                        be affected by my body heat.
2019-05-25_pair.txt4:   same, longer delay, and while aerating the room
```

The following measurements were made using a regulated power supply instead:

```
2019-05-25_pair5_voltagereg.txt:    same as before, but with regulated voltage
```

The following image shows the effect of the voltage regulation on the data:

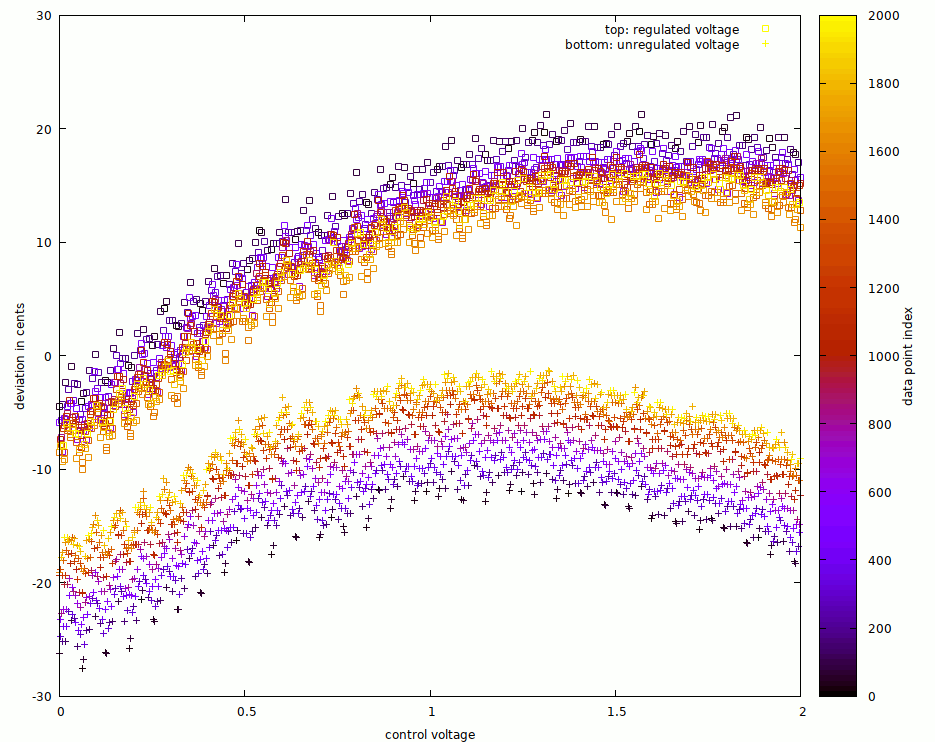
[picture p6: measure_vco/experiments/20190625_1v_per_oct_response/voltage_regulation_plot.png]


For the bottom graph without voltage regulation, the spread is much higher.
Furthermore, there is a quite linear-ish color gradient from purple (bottom)
to yellow (top), indicating that earlier data points are at a lower frequency
than late data points.

For the top graph with a regulated supply voltage, the spread / noise is
smaller, and the distribution seems more gaussian than uniform. Most
importantly, the color==time gradient is the opposite direction.

Possible explanation: The circuit's frequency depends on the supply voltage,
because the supply voltage controls the schmitt trigger thresholds. A lower
supply voltage leads to higher frequencies. The bottom graph could exhibit
the effects of a diminishing supply voltage, e.g. because the battery is
drained more and more.

The gradient for the top graph is yet to be explained. Measurement shows that
the control voltage applied to the expo converter's transistor's base is
always negative in this setup, ranging between -30mV and 0mV. During data
acquisition, the room temperature dropped a bit. (Let's say, from 303K to
300K). This changes the thermal voltage of the transistors by 1%, turning the
calibrated 1V-per-oct behaviour into 0.99V-per-oct. This, together with
the effective control voltage being negative, could explain a pitch drop
caused by a temperature drop. (For positive base-voltages, the pitch would
rise instead, and for exactly 0 V base-voltage, the pitch should not change).

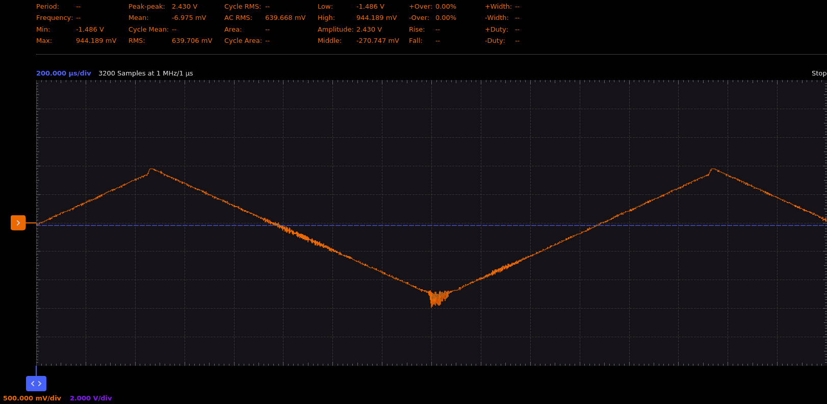
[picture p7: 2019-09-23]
measure_vco/experiments/20190922/breadboard2_2.5.png

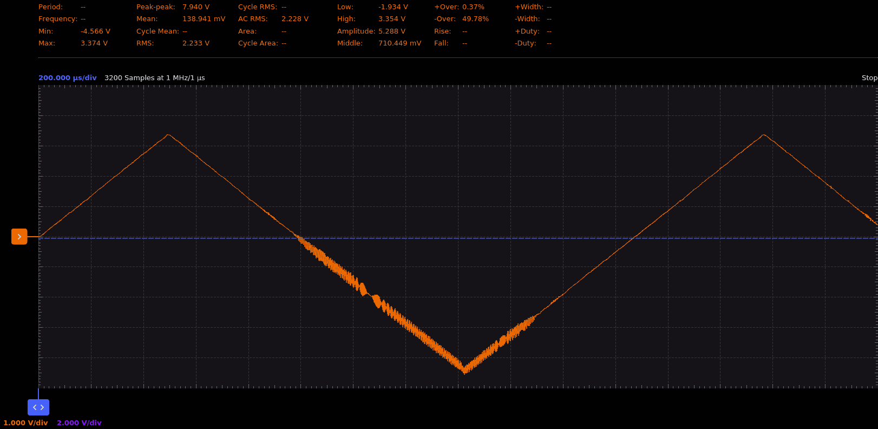
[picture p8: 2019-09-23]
measure_vco/experiments/20190922/breadboard4_8.0.png

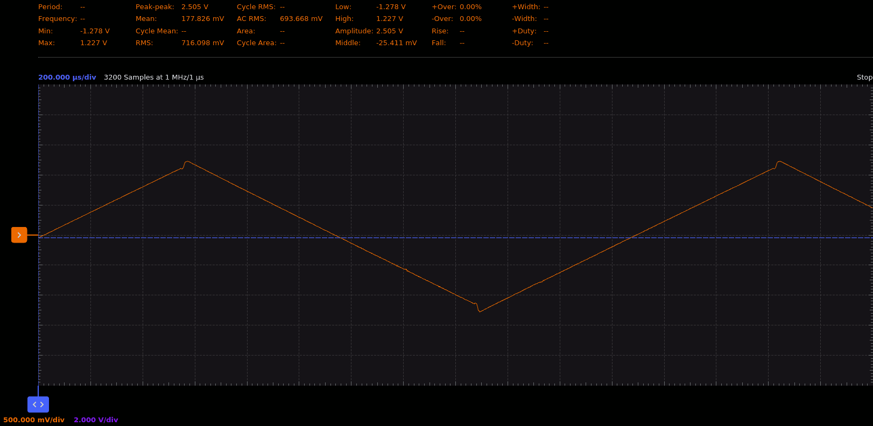
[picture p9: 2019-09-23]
measure_vco/experiments/20190922/red_2.5.png

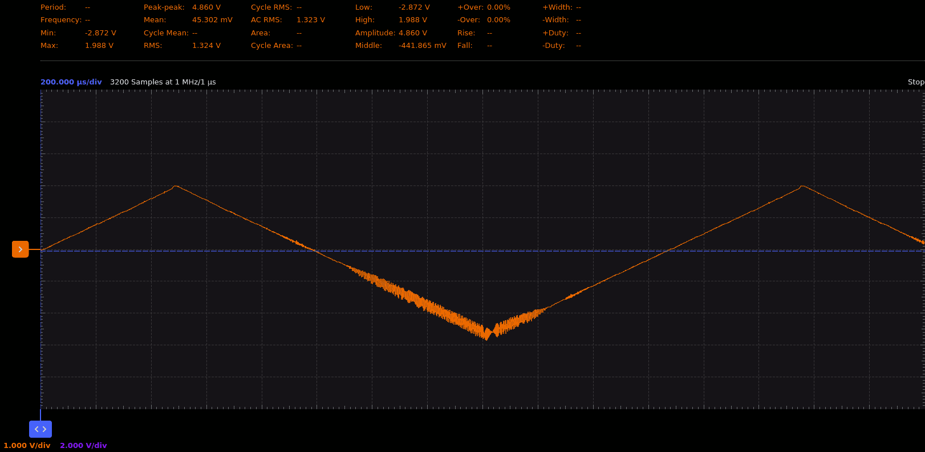
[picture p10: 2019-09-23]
measure_vco/experiments/20190922/breadboard1_5.0_000.png

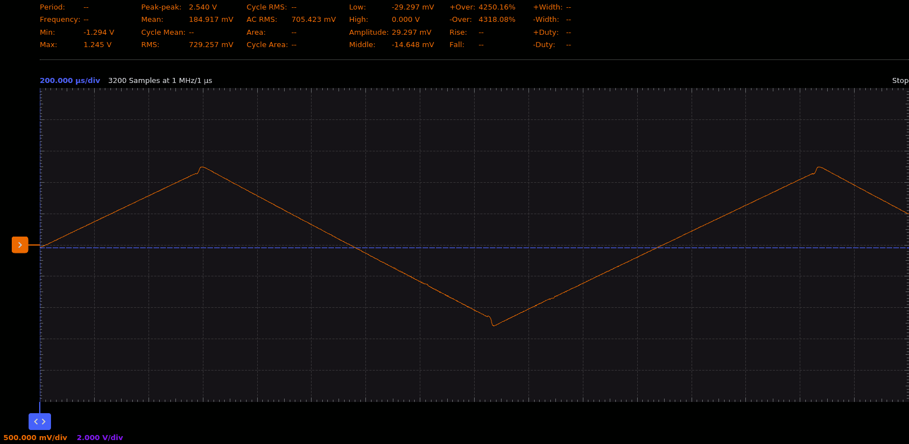
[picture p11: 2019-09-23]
measure_vco/experiments/20190922/blue_2.5.png

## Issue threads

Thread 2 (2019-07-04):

Add square ring modulator

Windfisch, 2019-07-04:
The sawtooth waveform is generated using "binary ring modulation" (i.e. by inverting the triangle's wave every half period).
Add an XOR gate (i.e., a digital multiplier) to allow binary ring modulation from outside.
Add a switch to switch between sawtooth and ring-modulated triangle.

Windfisch, 2019-08-19:
added.

Closed 2019-08-19.

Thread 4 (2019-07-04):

Automatic DAC steppiness compensation learning

Windfisch, 2019-07-04:
The DAC creates step-like artifacts every 64 code points.
- [x] they can be removed quite easily
- [ ] find an automatic way to remove them during self calibration
- [ ] do use this compensation strategy

Windfisch, 2019-11-08:
Compensation is implemented in the rust firmware.
No automatic steppiness compensation is implemented, instead, we sample every 64 code points. This automatically compensates the issue without explicitly modeling it.

Closed 2019-11-08.

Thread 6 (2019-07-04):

first order temperature compensation for the 1V-per-octave-trim

Windfisch, 2019-07-04:

Windfisch, 2019-08-19:
fixed

Closed 2019-08-19.

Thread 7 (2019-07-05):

High frequency trim

Windfisch, 2019-07-05:
Find out how to use the high frequency trim diode-resistor-combinations to resolve the volt-per-octave-tracking inaccuracy described [here](https://github.com/Windfisch/analog-synth/blob/673959eac2b995370ddffb885f70e904f58893d2/measure_vco/experiments/20190705_error_attribution/README.md)

Windfisch, 2019-07-06:
maybe an R_bulk issue, see [Sergio Franco's PhD thesis](https://ia801903.us.archive.org/1/items/hardwaredesignof677fran/hardwaredesignof677fran.pdf)

Windfisch, 2019-08-19:
Rossum compensation was implemented. For more details, see https://www.schmitzbits.de/expo_tutorial/ and search for "Rossum"

Closed 2019-08-19.

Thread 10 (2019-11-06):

Add output buffering to the square_ctl signal

Windfisch, 2019-11-06:
There is a emitter follower required to prevent the ring modulation circuitry (or any other consumer) to affect the frequency

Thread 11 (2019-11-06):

Add sync circuitry

Windfisch, 2019-11-06:
Sync works by manually applying 99%-duty-cycle PWM signals to the *sync* pin. Add circuitry to create these pulses from any input

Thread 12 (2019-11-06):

PWM ratio affects pitch

Windfisch, 2019-11-06:
Applying a LFO on the PWM ratio (regardless of whether the PWM signal is actually used or not) of VCO mk I slightly changes the pitch periodically.

Possible causes:
- GND is not perfect and thus is affected by the duty cycle / output signal of the comparator (see #13)
- OpAmp cross talk

Possible solutions:
- fix dirty ground wiring
- Change OpAmp
- Compensate using lin.pitchmod

Windfisch, 2019-11-08:
Caused by #13 and (temporarily) fixed by plugging the cable in different springs of the breadboard.

Closed 2019-11-08.

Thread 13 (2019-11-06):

Moving the ground wiring changes pitch

Windfisch, 2019-11-06:
up to half an octave!
This is likely due to the contact resistance of the cables.

Windfisch, 2019-11-08:
Seems to be a breadboard problem. Moving the cables into different slots fixes this for ca. 1 hour, then it starts getting worse.
Likely the springs are wearing out.

The cables itself, or their contact to the pin headers on the VCO board seem to be not an issue. :)

Closed 2019-11-08.

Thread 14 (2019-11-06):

Signal leaks through the closed VCA

Windfisch, 2019-11-06:
Leaking occurs even with the signal *not* being routed into the transistor's base terminal oO?
Leaking is stronger when a useless film capacitor is connected to the signal on the one side, floating on the other

Windfisch, 2019-11-08:
The signal does not leak through, but the VCA or rather, the differential-to-single-ended opamp picks up signals from the air.

It seems that the breadboard is the culprit, and also the 470uF-capacitors are both unneccessary and good antennas.

Windfisch, 2019-12-23:
This is still an issue with the new voice board.

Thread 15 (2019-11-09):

Design a control prototype board

Windfisch, 2019-11-09:
Features:
- Blue Pill socket
- 1-3x MCP4822
- 1-2x BU2505FV (plus 10x low pass filter)
- 4-16 signal shifters (0-5V to -2.5-2.5V for LFOs)
- Virtual ground generation
- Linear voltage regulator
- Capacitors
- LEDs. everyone loves them

Windfisch, 2019-11-09:
shift registers, e.g. for triggering external envelopes or leds. Just in case™!

Windfisch, 2019-11-30:
in production

Closed 2019-11-30.

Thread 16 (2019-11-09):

Design a voice supplement board

Windfisch, 2019-11-09:
Features:

- [x] mix 2-3 VCO signals
- [x] 1-3x sync circuitry
- [x] 1-3x square_ctl buffering
- [x] 1x VCA
- [x] 1x VCF (+feedback)
- [x] MCP4822
- [ ] sub oscillator
- [ ] layout board (stackable!) with separate grounds. they are joined in the main board.

Windfisch, 2019-11-09:
there should be support for fully analog VCOs (which can easily be implemented using VCO mk I)
also, for external analog envelope generators (possibly a not-yet-planned separate board)

Windfisch, 2019-11-09:
sub oscillator support! ;)

Windfisch, 2019-11-09:
make it stackable!

Windfisch, 2019-11-09:
maybe, put the MCP4822 onto this board, not on the control board.

Windfisch, 2019-11-30:
in production

Closed 2019-11-30.

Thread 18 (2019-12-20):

voice board: sync circuit does not generate a sync signal

Windfisch, 2019-12-20:
maybe the RC-highpass has a too high cutoff?

Windfisch, 2019-12-20:
R48,49 should be 1k instead of 10k

R50,51 should be 10k instead of 1k

Closed 2019-12-20.

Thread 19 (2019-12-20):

voice board: VCF does not work

Windfisch, 2019-12-20:
one transistor lane is 100mV below the other. no notable signal.
transistor mismatch? some error somewhere else?

Windfisch, 2019-12-20:
there was a solder bridge shorting Q11's collector and base terminals

Closed 2019-12-20.

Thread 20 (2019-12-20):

voice board: missing silkscreen

Windfisch, 2019-12-20:
- [x] J6
- [x] J8

Closed 2019-12-20.

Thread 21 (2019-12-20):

check voice board and main board

Windfisch, 2019-12-20:
voice board:

- [x] square_ctl buffering
- [x] clamping
- [x] sync pulse generation, see #18
- [x] VCF: broken, see #19
- [x] VCA
- [x] mixer
- [x] expo converter
- [x] Vctl generation

main board:
- [x] power generation
- [x] power distribution
- [x] STM32
- [x] DACs

Closed 2020-02-15.

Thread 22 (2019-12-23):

voice board's expo range is too low

Windfisch, 2019-12-23:

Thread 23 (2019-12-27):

voice board DAC overload

Windfisch, 2019-12-27:
The MCP4822 DAC is overloaded by the two 1k potis, yielding to negative steps in the frequency response:

```
Calibration data:
        0       10408324
        1       10412592        (+4268)
        2       10412996        (+404)
        3       10430552        (+17556)
        4       10461995        (+31443)
        5       10476525        (+14530)
        6       10471559        (+-4966)
        7       10485320        (+13761)
        8       10514117        (+28797)
        9       10531170        (+17053)
        10      10524266        (+-6904)
        11      10541212        (+16946)
        12      10571562        (+30350)
        13      10583441        (+11879)
        14      10582638        (+-803)
        15      10595078        (+12440)
        16      10623439        (+28361)
        17      10636119        (+12680)
        18      10629779        (+-6340)
        19      10646368        (+16589)
        20      10677762        (+31394)
        21      10690974        (+13212)
        22      10693401        (+2427)
        23      10703692        (+10291)
        24      10736802        (+33110)
        25      10750990        (+14188)
        26      10746097        (+-4893)
        27      10762025        (+15928)
        28      10793420        (+31395)
        29      10809007        (+15587)
        30      10806801        (+-2206)
        31      10821489        (+14688)
        32      10855301        (+33812)
        33      10868995        (+13694)
        34      10862854        (+-6141)
        35      10880101        (+17247)
        36      10909879        (+29778)
        37      10921666        (+11787)
        38      10920217        (+-1449)
        39      10935907        (+15690)
        40      10967428        (+31521)
        41      10980510        (+13082)
        42      10976635        (+-3875)
        43      10992054        (+15419)
        44      11022933        (+30879)
        45      11040306        (+17373)
        46      11036704        (+-3602)
        47      11054103        (+17399)
        48      11084608        (+30505)
        49      11102217        (+17609)
        50      11093039        (+-9178)
        51      11113498        (+20459)
        52      11140161        (+26663)
        53      11157024        (+16863)
        54      11152067        (+-4957)
        55      11165635        (+13568)
        56      11198119        (+32484)
        57      11214475        (+16356)
        58      11210262        (+-4213)
        59      11227953        (+17691)
        60      11257944        (+29991)
        61      11273733        (+15789)
        62      11267439        (+-6294)
        63      11283385        (+15946)
```

Unsoldering them and directly plugging the DAC's output into a 100k-impedance input solves this:

```
Calibration data:
        0       7560015
        1       7626153 (+66138)
        2       7685447 (+59294)
        3       7756073 (+70626)
        4       7815846 (+59773)
        5       7886242 (+70396)
        6       7946359 (+60117)
        7       8016541 (+70182)
        8       8074533 (+57992)
        9       8144614 (+70081)
        10      8204225 (+59611)
        11      8275233 (+71008)
        12      8334513 (+59280)
        13      8405362 (+70849)
        14      8467101 (+61739)
        15      8537092 (+69991)
        16      8596833 (+59741)
        17      8666389 (+69556)
        18      8725609 (+59220)
        19      8795968 (+70359)
        20      8854710 (+58742)
        21      8923339 (+68629)
        22      8981727 (+58388)
        23      9050377 (+68650)
        24      9110157 (+59780)
        25      9179110 (+68953)
        26      9238462 (+59352)
        27      9306614 (+68152)
        28      9367830 (+61216)
        29      9434346 (+66516)
        30      9494924 (+60578)
        31      9560891 (+65967)
        32      9622665 (+61774)
        33      9689127 (+66462)
        34      9748980 (+59853)
        35      9815773 (+66793)
        36      9876657 (+60884)
        37      9942616 (+65959)
        38      10003955        (+61339)
        39      10068704        (+64749)
        40      10130663        (+61959)
        41      10196342        (+65679)
        42      10256692        (+60350)
        43      10321702        (+65010)
        44      10382945        (+61243)
        45      10447593        (+64648)
        46      10508283        (+60690)
        47      10573012        (+64729)
        48      10634293        (+61281)
        49      10699242        (+64949)
        50      10759150        (+59908)
        51      10823672        (+64522)
        52      10884100        (+60428)
        53      10948259        (+64159)
        54      11010203        (+61944)
        55      11074036        (+63833)
        56      11136111        (+62075)
        57      11199193        (+63082)
        58      11259225        (+60032)
        59      11323721        (+64496)
        60      11383613        (+59892)
        61      11447449        (+63836)
        62      11507102        (+59653)
        63      11570118        (+63016)
```

Windfisch, 2021-01-31:
Fixed in 41341cb23bac400d2b9ff796438d530ec8d44693

Closed 2021-01-31.

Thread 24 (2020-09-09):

SPI clock noise

Windfisch, 2020-09-09:
The filter overlays the filtered signal with a nasty 1kHz signal. The SPI dacs update with 1kHz update rate. Changing this changes the hum.

Since SPICLK is running at 5MHz, and since touching the SPICLK pin with a large metal mass (such as a wirecutter) leads to amore pronounced hum.

This also happens with a proper 7805-7905-battery-based power supply, so likely not a virtual GND problem.

wrapping the filter in (grounded) aluminum foil strongly reduces the hum.

Seems like we have build a radio station :(

Windfisch, 2020-09-14:
to do:
- [ ] is the buzz still there without the actual transistor ladder connected? (i.e. only U1D with R36,37 dangling). (try this on the breadboard)
- [ ] does the buzz disappear when changing R36,37 and R42,43 to 100 / 10k?
- [ ] consider increasing the capacitors and the current passed through the ladder
- [ ] increase Vcc/Vee to ±12V

Windfisch, 2020-09-17:
Disconnect at C2:
-> buzz is visible on the oscilloscope at R21/R22.
-> buzz is also visible across C3 and C6
-> buzz is also visible at output

Disconnect R36,37
-> buzz is visible everywhere except the output

=> OpAmp isn't the issue. Transistor ladder and prescaling are both affected. wtf.

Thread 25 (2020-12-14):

Build metal enclosure

Windfisch, 2020-12-14:
Figure out whether the buzz goes away, when putting
- [ ] the main board or
- [ ] the voice board or
- [ ] both
into a metallic enclosure (or wrapped in aluminum foil)

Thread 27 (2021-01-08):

output level is *way* to low

Windfisch, 2021-01-08:
and connecting makes a nasty click, DC offset?

TODO: figure out how to properly do line-out.

Windfisch, 2021-02-02:
voiceboard-patch2 introducing the capacitors caused this. Removing them and applying patch-3 instead (buffering the transistor signals and changing to a 2-stage amplifier instead of one stage) fixed this.

Closed 2021-02-02.

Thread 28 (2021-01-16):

create final schematics (with less calibration potis)

Windfisch, 2021-01-16:
- [ ] VCO: remove var_vsrc, hard-wire schmitt_feedback and maybe even the tune poti
- [ ] voice board: get rid of all the trim potis; no filter overdrive (vca is enough)
- [ ] main board: figure out how to create the supply voltages
- [ ] put everything together, or at least put voltage converters on each board; or proper power distribution wiring.

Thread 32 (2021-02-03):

voltage controlled vca distortion and filter resonance

Windfisch, 2021-02-03:

Windfisch, 2021-02-07:
- [x] build a schematic in `simulation/`
- [x] allow changing the distortion without changing the overall volume
- [ ] replace single-transistor expo converters by double-transistor ones that are resistant against thermal changes.

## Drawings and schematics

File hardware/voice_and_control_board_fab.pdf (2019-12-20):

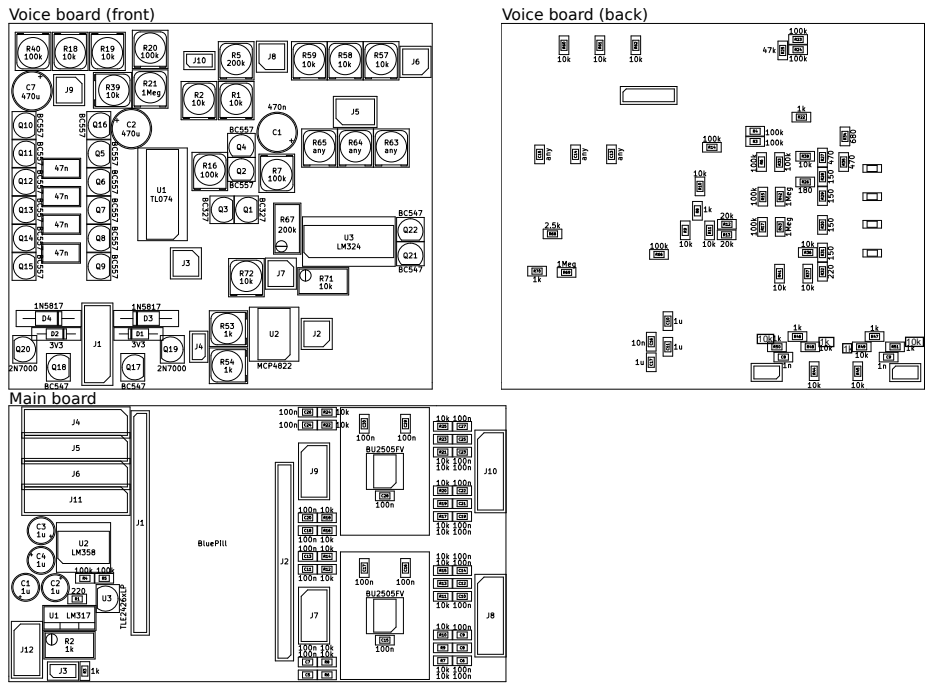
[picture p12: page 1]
Main board; Voice board (front); Voice board (back)

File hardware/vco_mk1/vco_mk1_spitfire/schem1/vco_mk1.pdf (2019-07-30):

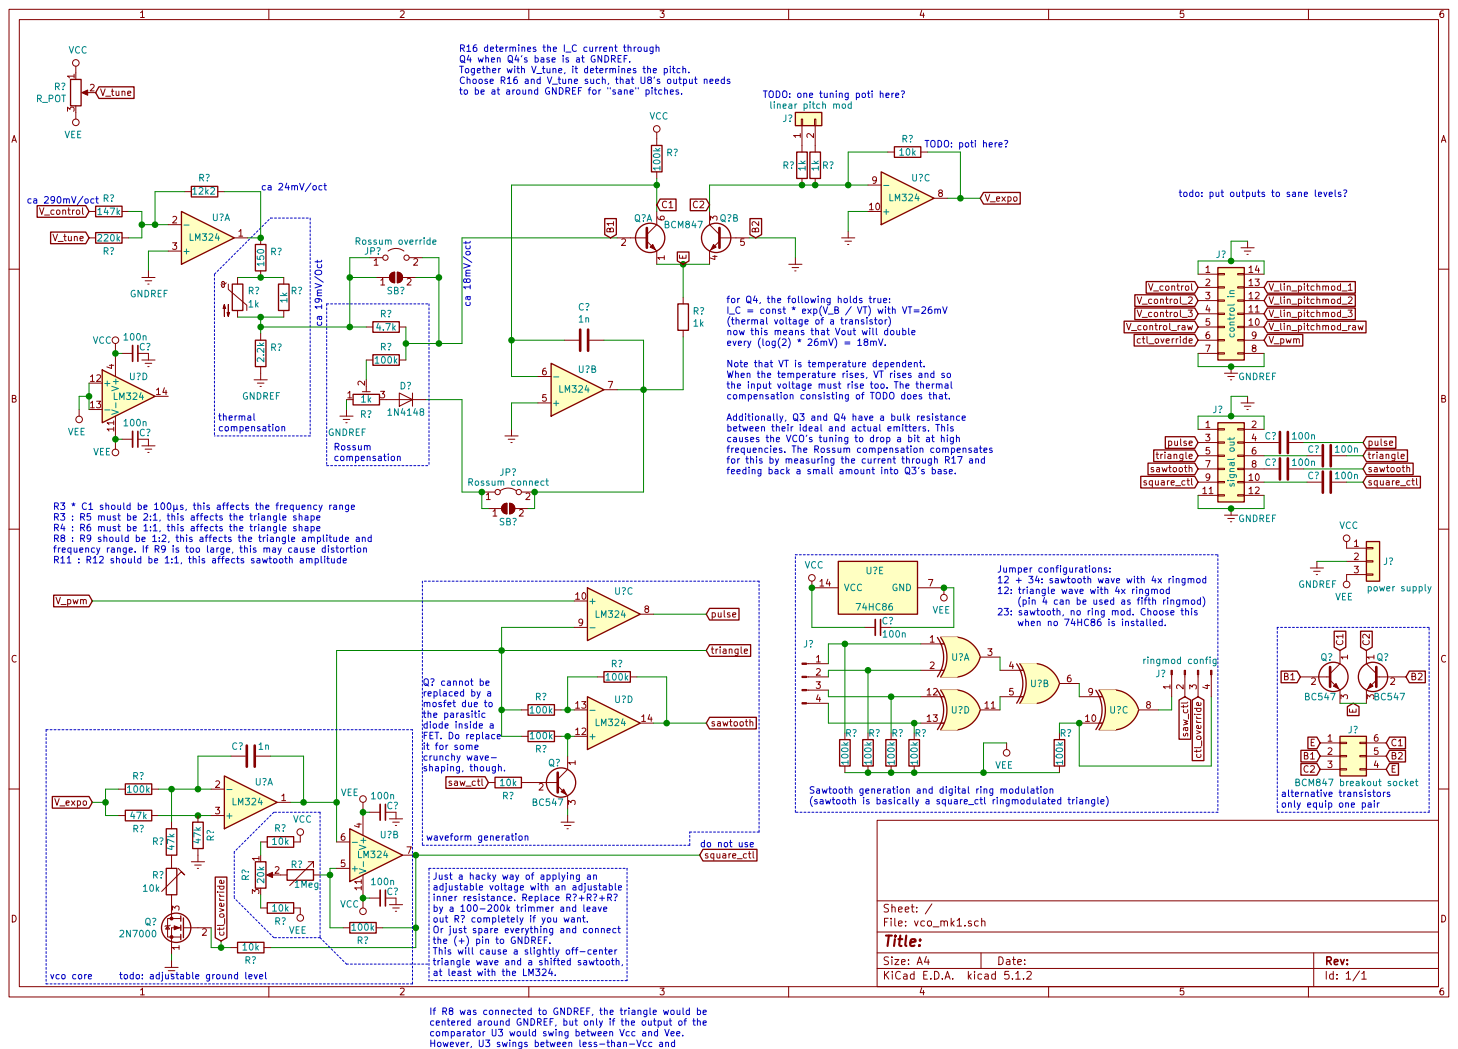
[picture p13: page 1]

R16 determines the I_C current through Q4 when Q4's base is at GNDREF. Together with V_tune, it determines the pitch.

Choose R16 and V_tune such, that U8's output needs

to be at around GNDREF for "sane" pitches. R?

TODO: one tuning poti here?
linear pitch mod R? 1k
1k VCC

for Q4, the following holds true:
I_C = const * exp(V_B / VT) with VT=26mV
(thermal voltage of a transistor) now this means that Vout will double

Note that VT is temperature dependent.
When the temperature rises, VT rises and so
the input voltage must rise too. The thermal
compensation consisting of TODO does that.

Additionally, Q3 and Q4 have a bulk resistance
between their ideal and actual emitters. This
causes the VCO's tuning to drop a bit at high
frequencies. The Rossum compensation compensates
for this by measuring the current through R17 and
feeding back a small amount into Q3's base.

alternative transistors only equip one pair VEE
VEE

do not use R3 * C1 should be 100µs, this affects the frequency range
R3 : R5 must be 2:1, this affects the triangle shape
R4 : R6 must be 1:1, this affects the triangle shape
R8 : R9 should be 1:2, this affects the triangle amplitude and
frequency range. If R9 is too large, this may cause distortion

power supply VEE GNDREF VCC

12 + 34: sawtooth wave with 4x ringmod
12: triangle wave with 4x ringmod
(pin 4 can be used as fifth ringmod)
23: sawtooth, no ring mod. Choose this
when no 74HC86 is installed. VEE

3 Q? BC547 Q? cannot be
replaced by a mosfet due to

the parasitic diode inside a FET. Do replace

Sawtooth generation and digital ring modulation
(sawtooth is basically a square_ctl ringmodulated triangle)

Just a hacky way of applying an
adjustable voltage with an adjustable
inner resistance. Replace R?+R?+R?
by a 100-200k trimmer and leave
out R? completely if you want.
Or just spare everything and connect
the (+) pin to GNDREF.
This will cause a slightly off-center
triangle wave and a shifted sawtooth, at least with the LM324.

todo: adjustable ground level

If R8 was connected to GNDREF, the triangle would be
centered around GNDREF, but only if the output of the
comparator U3 would swing between Vcc and Vee.
However, U3 swings between less-than-Vcc and

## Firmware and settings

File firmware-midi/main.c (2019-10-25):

#include <stdint.h>

#include <libopencm3/stm32/spi.h>
#include <libopencm3/stm32/rcc.h>
#include <libopencm3/stm32/gpio.h>
#include <libopencm3/stm32/usart.h>
#include <libopencm3/stm32/exti.h>
#include <libopencm3/stm32/timer.h>
#include <libopencm3/cm3/nvic.h>
#include <stdio.h>
#include <math.h>

#include "hardware.h"
#include "setup.h"
#include "usbmidi.h"

volatile int tim_meas_div = 1; // range: 1 - 65536. this equals tim_meas's prescaler plus 1. i.e. it's the number of mcu clocks per one timer tick

void delay_us(int us)
{
	const int tim_meas_clock = MCU_CLOCK / tim_meas_div;
	#define DELAY_MAX_COUNT 50000 // this has an ample margin to 65536

	uint16_t t0 = timer_get_counter(TIM_MEAS);
	uint16_t t1;

	int total_increments = ((uint64_t)us) * tim_meas_clock / 1000000;

	int takes = total_increments / DELAY_MAX_COUNT;
	total_increments = total_increments % DELAY_MAX_COUNT;

	for (int i=0; i<takes; i++)
	{
		do
		{
			t1 = timer_get_counter(TIM_MEAS);
		} while ( (uint16_t)(t1-t0) < DELAY_MAX_COUNT);
		t0 += DELAY_MAX_COUNT;
	}

	do
	{
		t1 = timer_get_counter(TIM_MEAS);
	} while ( (uint16_t)(t1-t0) < total_increments);
}

//-------------------------------------------------------------------------
// TIMER CONTROL
//-------------------------------------------------------------------------
// Usage:
//   1. use update_tim_meas_freq()
//   2. set n_measurements and measurement_time_limit accordingly
//      (usually, one wants to set one to UINT32_MAX)
//   3. set timer_state = WAITING
//   4. wait for timer_state becoming IDLE again
//   5. retrieve the results in measurements[], measurement_count and measurement_time.


// private variables
volatile uint16_t timer_begin; // [timer ticks]
volatile int timer_edge = EXTI_TRIGGER_RISING; // EXTI_TRIGGER_RISING or EXTI_TRIGGER_FALLING

// input variables
volatile enum { IDLE, WAITING, RUNNING } timer_state = IDLE;
volatile uint32_t n_measurements = 5;
volatile uint32_t measurement_time_limit = UINT32_MAX; // [timer ticks]

// output variables
volatile uint32_t measurement_count;
volatile uint32_t measurement_time; // [timer ticks]

#define MAX_MEASUREMENTS 1000
typedef struct
{
	volatile int high_time; // [timer ticks]
	volatile int low_time;  // [timer ticks]
} measurement_t;

volatile measurement_t measurements[MAX_MEASUREMENTS];

//-------------------------------------------------------------------------

void panic(void) { for(;;); }

void exti_meas_isr()
{
	uint16_t timer_val = timer_get_counter(TIM_MEAS);
	if (exti_get_flag_status(EXTI_MEAS))
	{
		exti_reset_request(EXTI_MEAS);
		
		switch (timer_edge)
		{
			case EXTI_TRIGGER_RISING:
				
				switch(timer_state)
				{
					case WAITING:
						timer_begin = timer_val;
						measurement_count = 0;
						measurement_time = 0;
						timer_state = RUNNING;
						break;

					case RUNNING:
					{
						uint16_t elapsed = timer_val - timer_begin; // this may underflow. this is fine.
						timer_begin = timer_val;

						measurements[measurement_count].low_time = elapsed;
						measurement_time += measurements[measurement_count].high_time + measurements[measurement_count].low_time;
						measurement_count++;

						if (measurement_count >= MAX_MEASUREMENTS || measurement_count >= n_measurements || measurement_time >= measurement_time_limit)
							timer_state = IDLE;

						break;
					}
					case IDLE:
						break;

				}

				exti_set_trigger(EXTI_MEAS, EXTI_TRIGGER_FALLING);
				timer_edge = EXTI_TRIGGER_FALLING;
				break;

			case EXTI_TRIGGER_FALLING:

				switch(timer_state)
				{
					case WAITING: break;
					case IDLE: break;
					case RUNNING:
					{
						uint16_t elapsed = timer_val - timer_begin; // this may underflow. this is fine.
						timer_begin = timer_val;

						measurements[measurement_count].high_time = elapsed;
					}
				}

				exti_set_trigger(EXTI_MEAS, EXTI_TRIGGER_RISING);
				timer_edge = EXTI_TRIGGER_RISING;
				
				break;

			default:
				panic();
		}
		//printf("exti7! %d\n", timer_val);
	}
	else
	{
		//printf("exti???\n");
	}
}


void dac_write(int val)
{
		gpio_clear(DAC_SS_PORT, DAC_SS_PIN); // slave select low
		spi_xfer(SPI_DAC, 0x0000 | 0x3000 | val);
		gpio_set(DAC_SS_PORT, DAC_SS_PIN); // slave select high
}

void play_note(int code)
{
	dac_write(code);

	//for (volatile int i=0; i<1000000; i++);
	delay_us(250000);
}

static unsigned reverse_bits(unsigned val, int n_bits)
{
	unsigned result = 0;
	for (int i=0; i<n_bits; i++)
	{
		if (val & (1<<i))
			result |= (1 << (n_bits-i-1));
	}
	return result;
}

void update_tim_meas_freq(uint32_t freq)
{
	int prescaler = (MCU_CLOCK+freq-1) / freq - 1; // round up
	if (prescaler > 0xFFFF) prescaler = 0xFFFF;
	if (prescaler < 0) prescaler = 0;

	tim_meas_div = prescaler+1;

	timer_disable_counter(TIM_MEAS);
	timer_set_prescaler(TIM_MEAS, prescaler);
	timer_generate_event(TIM_MEAS, TIM_EGR_UG); // force the prescaler preload register to be flushed into the active register
	timer_enable_counter(TIM_MEAS);
}


// ---------- frequency expectation ----------

#define PROBE1 1024
#define PROBE2 3096
int probe1_freq, probe2_freq;

void init_frequency_expectations()
{
	// measure the frequencies at PROBE1 and PROBE2 in order to feed the expected_frequency() helper function
	update_tim_meas_freq(10); // this is a very conservative value, yielding bad resolution but no risk of overflowing the timer.
	dac_write(PROBE1);
	timer_state = WAITING;
	while (timer_state != IDLE); // wait for the measurement to complete
	probe1_freq = MCU_CLOCK * measurement_count / tim_meas_div / measurement_time;
	dac_write(PROBE2);
	timer_state = WAITING;
	while (timer_state != IDLE); // wait for the measurement to complete
	probe2_freq = MCU_CLOCK * measurement_count / tim_meas_div / measurement_time;
	printf("freq at %d is %d, freq at %d is %d\n", PROBE1, probe1_freq, PROBE2, probe2_freq);
}

int expected_frequency(int codepoint)
{
	float octaves = log2(probe2_freq/ (float) probe1_freq); // octaves across PROBE1 .. PROBE2
	return probe1_freq * exp2(octaves * (float)(codepoint-PROBE1) / (float)(PROBE2-PROBE1));
}

int expected_codepoint(float freq)
{
	float octaves = log2(probe2_freq/ (float) probe1_freq); // octaves across PROBE1 .. PROBE2
	return log2(freq / probe1_freq) / octaves * (PROBE2-PROBE1) + PROBE1;
}

// requires that init_frequency_expectations() has been called before
// measures n cycles and returns the frequency.
// side effects: fills measurements and associated variables.
float measure_frequency_at_codepoint(int codepoint, int n)
{
	measurement_time_limit = UINT32_MAX;
	n_measurements = n;
	update_tim_meas_freq( expected_frequency(codepoint) * 2 * 30000 ); // that leaves an octave room for misjudgement. 30000 ~= 2**16 / 2
	dac_write(codepoint);

	timer_state = WAITING;
	while (timer_state != IDLE); // wait for the measurement to complete.

	return ((float)MCU_CLOCK) / tim_meas_div / measurement_time * measurement_count;
}

// accuracy: maximum frequency deviation relative to freq. use 0.003 for 5 cent accuracy
int search_codepoint_for_frequency(float freq, float accuracy, int n, int max_iter)
{
	int codepoint = expected_codepoint(freq);
	
	printf("searching for %f Hz\n", freq);

	int codepoint_error;
	float actual_freq;
	int i = 0;
	do
	{
		if (codepoint < 0) codepoint = 0;
		if (codepoint >= 4096) codepoint = 4095;
		if (i++ > max_iter)
			break;
		printf("trying codepoint %i", codepoint);
		actual_freq = measure_frequency_at_codepoint(codepoint, n);
		codepoint_error = expected_codepoint(freq) - expected_codepoint(actual_freq);
		printf(" -> freq is %f Hz -> need to shift by %+i\n", actual_freq, codepoint_error);
		codepoint += codepoint_error;
	} while (codepoint_error != 0 && !(freq/actual_freq <= (1.f + accuracy) && actual_freq/freq <= (1.f + accuracy)));
	
	printf("result: %f is at %d\n", actual_freq, codepoint);

	return codepoint;
}

void measure_frequency_stability(float target_freq)
{
	int codepoint = search_codepoint_for_frequency(target_freq, 0.000, 10, 100);
	printf("code point is %d\n", codepoint);

	update_tim_meas_freq( target_freq * 2 * 30000 ); // that leaves an octave room for misjudgement. 30000 ~= 2**16 / 2
	measurement_time_limit = MCU_CLOCK / tim_meas_div;
	n_measurements = MAX_MEASUREMENTS;
	dac_write(codepoint);

	timer_state = WAITING;
	while (timer_state != IDLE); // wait for the measurement to complete.
	
	printf("done, took %d measurements\n", measurement_count);
	// print the result
	printf("%4d %6d ", codepoint, tim_meas_div);
	for (uint32_t i=0; i<measurement_count; i++)
		printf("  %8d %8d", measurements[i].low_time, measurements[i].high_time);
	printf("\n");
}
// ---------- main code ----------

static void buf_write(int channel, int val)
{
	int channel_rev = reverse_bits(channel, 4);
	printf("buf_write channel %d aka %d, val %d -> %2x\n", channel, channel_rev, val, (channel_rev << 10) | (val & 0x3FF));
	spi_xfer(SPI_DAC, (channel_rev << 10) | (val & 0x3FF));
	for (volatile int i=0; i<10; i++);
	gpio_set(BUF_LD_PORT, BUF_LD_PIN);
	for (volatile int i=0; i<10; i++);
	gpio_clear(BUF_LD_PORT, BUF_LD_PIN);
}

static void test_buf_dac()
{
	while(true)
		for (int i=0; i<1024; i+=16)
		{
			buf_write(2, i);
			myusb_poll();
		}
}

extern int current_note, retrigger_note, release_note;

int main(void)
{
	setup();

	myusb_init();
	for (int i=0; i<500000; i++)
	{
		myusb_poll();
	}
	
	// blink the LED
	gpio_clear(LED_GPIO, LED_PIN);
	for (volatile int i = 0; i<1000000; i++);
	gpio_set(LED_GPIO, LED_PIN);


	// measure the frequencies at PROBE1 and PROBE2 in order to feed the expected_frequency() helper function
	init_frequency_expectations();


	play_note(0);
	play_note(100);
	play_note(4095);
	play_note(4095 - 100);

	measure_frequency_stability(440);

	//test_buf_dac();

	int envelope_value = 1023;
	while(true)
	{
		myusb_poll();
		if (retrigger_note)
		{
			float freq = pow(2, (current_note - 0x40)/12.0) * 440;
			printf("triggering note %d at %f Hz\n", current_note, freq);
			search_codepoint_for_frequency(freq, 0, 10, 100);
			envelope_value = 1023;
			retrigger_note = 0;
		}

		if (release_note)
		{
			envelope_value -= 4;
			if (envelope_value < 0) envelope_value = 0;
		}

		buf_write(2, 1023-envelope_value);
	}


	measure_frequency_stability(110);
	measure_frequency_stability(220);
	measure_frequency_stability(440);
	measure_frequency_stability(880);
	measure_frequency_stability(1320);
	measure_frequency_stability(1760);


	while(true)
	for (int i=0; i<4096; i++)
	{
		myusb_poll();
		int pitch_val = reverse_bits(i, 12);
		//int pitch_val = (i*64) % 4096;

		measure_frequency_at_codepoint(pitch_val, 5);

		// print the result
		printf("%4d %6d ", pitch_val, tim_meas_div);
		for (uint32_t j=0; j<measurement_count; j++)
			printf("  %8d %8d", measurements[j].low_time, measurements[j].high_time);
		printf("\n");
	}
	printf("end\n");
	panic();
}

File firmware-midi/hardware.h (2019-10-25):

	#ifdef STM32F103C8T

// blue pill aka STM32F103C8T

#define MCU_CLOCK  72000000 // 72 MHz

#define USART_DEBUG USART1
#define RCC_USART_DEBUG RCC_USART1

#define TIM_MEAS TIM2
#define RCC_TIM_MEAS RCC_TIM2
#define RST_TIM_MEAS RST_TIM2

// USB: PA11 and PA12

#define EXTI_MEAS EXTI15
#define EXTI_MEAS_PIN GPIO15
#define EXTI_MEAS_GPIO GPIOA
#define exti_meas_isr exti15_10_isr
#define NVIC_EXTI_MEAS_IRQ NVIC_EXTI15_10_IRQ


#define LED_GPIO GPIOC
#define LED_PIN GPIO13

// The SPI bus with the DAC
#define DAC_SS_PORT GPIOB
#define DAC_SS_PIN GPIO12

#define BUF_LD_PORT GPIOB
#define BUF_LD_PIN GPIO14

#define SPI_DAC SPI2 // using PB13==clock and PB15==mosi
#define RCC_SPI_DAC RCC_SPI2

#elif defined(STM32F411RE)

// STM32F411 discovery

#define MCU_CLOCK  84000000 // 72 MHz

#define USART_DEBUG USART2
#define RCC_USART_DEBUG RCC_USART2

#define TIM_MEAS TIM2
#define RCC_TIM_MEAS RCC_TIM2
#define RST_TIM_MEAS RST_TIM2

#define EXTI_MEAS EXTI7
#define EXTI_MEAS_PIN GPIO7
#define EXTI_MEAS_GPIO GPIOE
#define exti_meas_isr exti9_5_isr
#define NVIC_EXTI_MEAS_IRQ NVIC_EXTI9_5_IRQ


#define LED_GPIO GPIOD
#define LED_PIN GPIO12

// The SPI bus with the DAC
#define DAC_SS_PORT GPIOE
#define DAC_SS_PIN GPIO13

#define SPI_DAC SPI4 // using PE12 and PE14 as SCK/MOSI
#define RCC_SPI_DAC RCC_SPI4

#endif

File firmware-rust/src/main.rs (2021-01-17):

#![no_std]
#![no_main]

extern crate panic_semihosting;

mod envelope;
mod reverse_bits;
mod bu2505fv;

use rtfm::app;

use stm32f1xx_hal::{prelude::*, stm32, gpio::*, serial, timer, spi};

use embedded_hal::digital::v2::OutputPin;

use embedded_hal::digital::v1_compat::OldOutputPin;

#[macro_use(singleton)]
extern crate cortex_m;

use cortex_m::asm::delay;
use cortex_m_rt::entry;
use stm32::interrupt;

use usb_device::prelude::*;
use stm32_usbd::UsbBus;
use usbd_midi;
mod midi;
mod vco;

use core::cell::RefCell;

use core::fmt::Write;
use core::mem::MaybeUninit;

mod coop_threadsafe_container; use coop_threadsafe_container as ctc;
use ctc::ThreadToken;

use mcp49xx;
use shared_bus;
use noop_bus_mutex;

static mut GLOB_EXTI_PIN : MaybeUninit<gpioa::PA7<Input<Floating>>> = MaybeUninit::uninit();
static mut GLOB_TX : MaybeUninit<serial::Tx<stm32::USART1>> = MaybeUninit::uninit();
static mut GLOB_TIMER : MaybeUninit<timer::CountDownTimer<stm32::TIM2>> = MaybeUninit::uninit();

static PINGPONG : ctc::CoopContainer<vco::MeasurementState> = ctc::CoopContainer::new(  vco::MeasurementState::const_default(), ctc::Token::<ctc::Main>::ID);



type MyUsbPins = (stm32f1xx_hal::gpio::gpioa::PA11<stm32f1xx_hal::gpio::Input<stm32f1xx_hal::gpio::Floating>>, stm32f1xx_hal::gpio::gpioa::PA12<stm32f1xx_hal::gpio::Input<stm32f1xx_hal::gpio::Floating>>);
type MyUsbBus = stm32_usbd::bus::UsbBus<MyUsbPins>;

type MySpiPins = (
	gpiob::PB13<Alternate<PushPull>>,
	gpiob::PB14<Input<Floating>>,
	gpiob::PB15<Alternate<PushPull>>
);

type MySpi = stm32f1xx_hal::spi::Spi<
	stm32::SPI2,
	MySpiPins
>;

type MySharedSpiManager = shared_bus::proxy::BusManager<
	noop_bus_mutex::NoopBusMutex<
		core::cell::RefCell<
			MySpi
		>
	>,
	MySpi
>;
type MySharedSpiProxy = shared_bus::proxy::BusProxy<'static,
	noop_bus_mutex::NoopBusMutex<
		core::cell::RefCell<
			MySpi
		>
	>,
	MySpi
>;

type Mcp = mcp49xx::Mcp49xx<
	mcp49xx::interface::SpiInterface<
		MySharedSpiProxy,
		OldOutputPin<Pxx<Output<PushPull>>>
	>,
	mcp49xx::marker::Resolution12Bit,
	mcp49xx::marker::DualChannel,
	mcp49xx::marker::Unbuffered
>;

type VcoType = vco::VoltageControlledOscillator<'static, Mcp>;

pub struct SpiDevices {
	vcos : [VcoType; 2],
	envelope : envelope::Envelope,
	bu2505 : bu2505fv::Bu2505fv<MySharedSpiProxy, Pxx<Output<PushPull>>, bu2505fv::Reversed>,
	spi_accessor : MySharedSpiProxy
}

static mut SPI_DEVICES : MaybeUninit<SpiDevices> = MaybeUninit::uninit();

mod vco_token { // TODO FIXME rename this
	use crate::{SpiDevices, SPI_DEVICES};
	pub struct VcoToken { dummy : () }
	impl VcoToken {
		pub const unsafe fn new() -> VcoToken { VcoToken{dummy:()} }
	}
	pub fn vcos<'a>(token : &'a mut VcoToken) -> &'a mut SpiDevices {
		unsafe { &mut *SPI_DEVICES.as_mut_ptr() }
	}
}

use crate::vco_token::{VcoToken,vcos};

#[derive(Debug)]
enum Command {
	Calibrate,
	Midi(midi::MidiChannelMessage)
}

use stm32f1xx_hal::time::Hertz;
const SYSCLK : Hertz = Hertz(72_000_000);

#[app(device = stm32)]
const APP: () = {
	struct Resources {
		// TODO
		#[init(())]
		dummy : (),
		exti : stm32::EXTI,
		#[init(core::ptr::null_mut())]
		exti_pin_ptr : *mut Pxx<Input<Floating>>,
		tx : serial::Tx<stm32::USART1>,
		led : gpioc::PC13<Output<PushPull>>,
		usb_dev : usb_device::device::UsbDevice<'static, MyUsbBus>,
		midi : usbd_midi::MidiClass<'static, MyUsbBus>,
		mytimer : timer::CountDownTimer<stm32::TIM2>,
		env_timer : timer::CountDownTimer<stm32::TIM1>,
		#[init(false)]
		calibration_in_progress : bool,
		#[init(envelope::Envelope::new())]
		test_env1 : envelope::Envelope,
		test_env2 : envelope::Envelope,
		test_lfo1 : envelope::Envelope,
		test_lfo2 : envelope::Envelope,
		#[init( unsafe{VcoToken::new()} )]
		vco_token : VcoToken
	}

	//#[init(resources=[vco_token])]
	#[init(spawn=[xmain],resources=[vco_token])]
	fn init(mut cx : init::Context) -> init::LateResources {
		static mut USB_BUS: Option<usb_device::bus::UsbBusAllocator<MyUsbBus>> = None;

		let dp = stm32::Peripherals::take().unwrap();
		let p = &mut cx.core; //cortex_m::peripheral::Peripherals::take().unwrap();


		// Clock configuration

		let mut flash = dp.FLASH.constrain();
		let mut rcc = dp.RCC.constrain();

		let clocks = rcc.cfgr
			.use_hse(8.mhz())
			.sysclk(SYSCLK)
			.pclk1(36.mhz())
			.freeze(&mut flash.acr);

		assert!(clocks.usbclk_valid());


		// GPIO and peripheral configuration

		let mut afio = dp.AFIO.constrain(&mut rcc.apb2);
		let mut gpioa = dp.GPIOA.split(&mut rcc.apb2);
		let mut gpiob = dp.GPIOB.split(&mut rcc.apb2);
		let mut gpioc = dp.GPIOC.split(&mut rcc.apb2);

		// Configure the on-board LED (PC13, green)
		let mut led = gpioc.pc13.into_push_pull_output(&mut gpioc.crh);
		led.set_high().ok(); // Turn off

		// Configure the USART
		let gpio_tx = gpioa.pa9.into_alternate_push_pull(&mut gpioa.crh);
		let gpio_rx = gpioa.pa10;
		let serial = serial::Serial::usart1(
			dp.USART1,
			(gpio_tx, gpio_rx),
			&mut afio.mapr,
			serial::Config::default().baudrate(115200.bps()),
			clocks,
			&mut rcc.apb2
		);
		let (mut tx, _rx) = serial.split();
		writeln!(tx, "usart initialized").ok();
		writeln!(tx, "========================================================").ok();
		writeln!(tx, "analog-synth @ {}", env!("VERGEN_SHA")).ok();
		writeln!(tx, "      built on {}", env!("VERGEN_BUILD_TIMESTAMP")).ok();
		writeln!(tx, "========================================================\n").ok();
		
		// Configure USB
		// BluePill board has a pull-up resistor on the D+ line.
		// Pull the D+ pin down to send a RESET condition to the USB bus.
		let mut usb_dp = gpioa.pa12.into_push_pull_output(&mut gpioa.crh);
		usb_dp.set_low().ok();
		delay(clocks.sysclk().0 / 100);
		
		let usb_dm = gpioa.pa11;
		let usb_dp = usb_dp.into_floating_input(&mut gpioa.crh);

		*USB_BUS = Some( UsbBus::new(dp.USB, (usb_dm, usb_dp)) );
		let usb_bus = USB_BUS.as_ref().unwrap();

		let mut midi = usbd_midi::MidiClass::new(usb_bus);
		let mut usb_dev = UsbDeviceBuilder::new(usb_bus, UsbVidPid(0x16c0, 0x27dd))
			.manufacturer("Fake company")
			.product("Serial port")
			.serial_number("TEST")
			.device_class(usbd_midi::USB_CLASS_NONE)
			.build();
			
		writeln!(tx, "spi...");

		// SPI
		let mcp_ss : OldOutputPin<_> = gpiob.pb12.into_push_pull_output(&mut gpiob.crh).downgrade().into();
		let mcp2_ss : OldOutputPin<_> = gpiob.pb11.into_push_pull_output(&mut gpiob.crh).downgrade().into();
		let sck = gpiob.pb13.into_alternate_push_pull(&mut gpiob.crh);
		let mosi = gpiob.pb15.into_alternate_push_pull(&mut gpiob.crh);
		let miso = gpiob.pb14;

		let spi = spi::Spi::spi2(dp.SPI2, (sck, miso, mosi), spi::Mode { phase : spi::Phase::CaptureOnFirstTransition, polarity : spi::Polarity::IdleLow }, 5.mhz(), clocks, &mut rcc.apb1);
		let shared_spi : &'static MySharedSpiManager = singleton!(:MySharedSpiManager =
			shared_bus::BusManager::<noop_bus_mutex::NoopBusMutex<_>, _>::new(spi)
		).unwrap();
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

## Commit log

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2019-05-30 fixed that shit
    [vco.sch]
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2019-05-30 sawtooth broken?
    [vco.sch]
2019-05-30 add comments, fix frequency range
    [vco.sch]
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2019-06-09 rotate R3 and C1
    [vco.sch]
2019-06-28 vco: add hint about mosfet as Q1
    [vco.sch]
2019-06-28 vco: adapt sawtooth generation to actual ciruitry on the breadboard
    [vco.sch]
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2019-06-30 test tones for adjusting R10
    [measure_vco.sch]
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2019-07-28 measure_vco schematic: reality update
    [measure_vco.sch]
2019-07-28 schematic: add thermal and rossum compensation
    [measure_vco.sch]
2019-07-28 vco_mk1 schematic. nearly finished
    [vco_mk1.kicad_pcb, vco_mk1.sch]
2019-07-29 add buffer to measure_vco schematic
    [measure_vco.sch]
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2019-07-29 vco_mk1: add triangle center and amplitude potis
    [vco_mk1.sch]
2019-07-30 vco_mk1: eliminated last structural todos
    still todo: value selection
    [vco_mk1.sch]
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2019-07-30 remove duplicate solder bridges
    [vco_mk1.sch]
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2019-08-03 fix XOR schematic
    [vco_mk1.sch]
2019-08-03 better ring modulation. improved comments
    [vco_mk1.sch]
2019-08-03 annotate and add footprints
    [vco_mk1.sch]
2019-08-04 add high pass filter for sawtooth/square generation
    this fixes sawtooth/square generation when running
    in DCO mode.
    [vco_mk1.sch]
2019-08-04 add comment about deepmind-ish square variation
    [vco_mk1.sch]
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2019-08-06 confirmed: vco core and waveform generation (and fixes)
    [vco_mk1.sch]
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2019-08-07 vco1.sch confirmed.
    TODO: check designated values for R13, R14, R19, C3
    [vco_mk1.sch]
2019-08-08 triangle center adjust: add 0-Ohm-resistor to GNDREF
    [vco_mk1.sch]
2019-08-10 resolved last todo
    [vco_mk1.sch]
2019-08-10 the great component name overhaul
    [vco_mk1.sch]
2019-08-10 fix bug with pulse ring modulation
    [vco_mk1.sch]
2019-08-10 working config with clean slate PCB
    [vco_mk1.kicad_pcb, vco_mk1_old.kicad_pcb]
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2019-08-10 grouped all components into logical groups
    [vco_mk1.kicad_pcb]
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2019-08-10 rough layout for U3
    [vco_mk1.kicad_pcb]
2019-08-10 rough layout for U2
    [vco_mk1.kicad_pcb]
2019-08-10 rough layout for U1
    [vco_mk1.kicad_pcb]
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2019-08-11 first pass layout clusterfuck
    [vco_mk1.kicad_pcb]
2019-08-11 improved grounding a bit
    [vco_mk1.kicad_pcb]
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2019-08-11 tweaket copper pour clearance
    [vco_mk1.kicad_pcb]
2019-08-11 clean slate reroute with cleaner layout
    [vco_mk1.kicad_pcb]
2019-08-11 shrink gndplane, add texts
    [vco_mk1.kicad_pcb]
2019-08-11 shrink edge cuts, fix texts
    [vco_mk1.kicad_pcb]
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2019-08-12 new routing for improved placement
    [vco_mk1.kicad_pcb]
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2019-08-12 added silkscreen labels and logos
    [vco_mk1.kicad_pcb]
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2019-08-12 final version and gerber files
    [vco_mk1-B_Cu.gbr, vco_mk1-B_Mask.gbr, vco_mk1-B_SilkS.gbr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]
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2019-08-12 added README and updated file structure to new naming conventions
    [vco_mk1-B_Cu.gbr, vco_mk1-B_Mask.gbr, vco_mk1-B_SilkS.gbr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]
2019-08-12 rename vco_mk1 board -> vco_mk1_windfisch
    [vco_mk1-B_Cu.gbr, vco_mk1-B_Mask.gbr, vco_mk1-B_SilkS.gbr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]
2019-08-19 fix component references in schematic descriptions
    [vco_mk1.sch]
2019-08-19 be clear about schematic variants
    [vco_mk1.sch]
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2019-09-15 fix printf %f
2019-09-15 measure the frequency stability at various pitches
    [main.c]
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2019-10-25 fix dac pins, refactor midi firmware
    [hardware.h, main.c, setup.c]
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2019-10-25 fix some bugs and warnings
    [main.rs]
2019-10-29 this does not work...
    [main.rs, vco.rs]
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2019-11-03 schematic for the new firmware setup
    [schem.kicad_pcb, schem.sch, vca.sch]
2019-11-09 working VCF (npn variant)
    [schem.sch]
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2019-11-12 proper VCF ctl input stage
    [voice_board.sch]
2019-11-12 general purpose filters, VCA input stage
    [voice_board.sch]
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2019-11-13 add pre-bias poti for the VCF
    [voice_board.sch]
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2019-11-13 put measurement clamping circuitry on the voice board
    [control_board_prototype.sch, voice_board.sch]
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2019-11-14 voice board: footprint association
    [voice_board.sch]
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2019-11-15 voice board: fixes, vca layout
    [voice_board.kicad_pcb, voice_board.sch]
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2019-11-15 mixer and lowpass filters
    [voice_board.kicad_pcb, voice_board.sch]
2019-11-16 finished layout for all individual sections
    [voice_board.kicad_pcb, voice_board.sch]
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2019-11-17 fix voice board: add power to the OpAmp -.-
    [voice_board.sch]
2019-11-17 fix voice board: layout
    [voice_board.kicad_pcb]
2019-11-17 voice board: add expo
    [expo.sch, voice_board.sch]
2019-11-17 minor fixes
    [voice_board.kicad_pcb, voice_board.sch]
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2019-11-18 flip footprint
    [voice_board.kicad_pcb, voice_board.sch]
2019-11-18 flip another footprint
    [voice_board.kicad_pcb, voice_board.sch]
2019-11-18 replace some SMD caps with thts
    [voice_board.kicad_pcb, voice_board.sch]
2019-11-18 flip some potis
    [voice_board.kicad_pcb, voice_board.sch]
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2019-11-19 move most things together
    [voice_board.kicad_pcb]
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2019-11-21 move VCF poti to VCF side
    [voice_board.kicad_pcb, voice_board.sch]
2019-11-21 fix todos
    [voice_board.sch]
2019-11-21 fix vca output
    [voice_board.kicad_pcb, voice_board.sch]
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2019-11-22 use film caps for the filter
    [voice_board.kicad_pcb, voice_board.sch]
2019-11-22 increase spacing of the filter
    [voice_board.kicad_pcb]
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2019-11-23 final version of voice board mk I
    [voice_board.kicad_pcb, voice_board.sch]
2019-11-23 voice board: towards production
    [bom.ods, voice_board.kicad_pcb, voice_board.sch]
2019-11-23 fabrication files and readme for voice board
    [voice_board-B_Cu.gbr, voice_board-B_Mask.gbr, voice_board-B_Paste.gbr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]
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2019-11-24 last fixes for control and voice board:
    control board: add 3V3 header
    voice board: mcp4822 silkscreen
    [control_board_prototype-B_Cu.gbr, control_board_prototype-B_Mask.gbr, control_board_prototype-B_Paste.gbr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]
2019-11-28 fix 3d models in footprint library
2019-11-28 fix paths to schematic and footprint libraries
2019-11-28 update footprints in boards, use local runtron 3d model (on my machine only)
    [control_board_prototype.kicad_pcb, vco_mk1.kicad_pcb, voice_board.kicad_pcb]
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2019-12-07 pretty fabrication layers for voice and control board
    [control_board_prototype.kicad_pcb, voice_board.kicad_pcb]
2019-12-16 control board docs and rev02
    [control_board_prototype.kicad_pcb]
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2019-12-20 voice board errata
2019-12-20 Fix swapped resistors in voice board's sync circuit
    Fixes #18
    [voice_board.kicad_pcb, voice_board.sch]
2019-12-20 voice board: silk screen fixes
    Fixes #20
    [voice_board.kicad_pcb]
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2019-12-20 control board: more silk screen fixes
    [control_board_prototype.kicad_pcb]
2019-12-27 schematic fixes
2019-12-27 add BU2505 dac channel labels
    [control_board_prototype.kicad_pcb]
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2020-02-13 vcf simulation. does not work
    [vcf.sch]
2020-02-15 vcf simulation works :)
    [vcf.sch]
2020-09-08 some VCF schematic changes
    [vcf.sch]
2021-01-16 voice board: remove DAC potis, tie down dangling op amp
    [voice_board.sch]
2021-01-16 updated resistor values to match current situation
    [voice_board.sch]
2021-01-16 add capacitors in an attempt to fix the buzzing
    [voice_board.sch]
2021-01-17 reality update for the control board:
    - reduce R4/R5 from 100k to 2.2k
    - capacitors across R5 and U1
    - protection diode for U1
    - source termination resistor for SCK signal
    [control_board_prototype.sch]
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2021-01-31 vcf_unbuffered_capacitors* now correctly reflect patch2
    [vcf_unbuffered_capacitors1.sch, vcf_unbuffered_capacitors2.sch]
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2021-02-07 vca with voltage controlled distortion that does not affect volume
    [vca.sch]
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2021-02-09 thermally compensated expo current source for VCA, pinch off resistor
    [vca.sch]
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
